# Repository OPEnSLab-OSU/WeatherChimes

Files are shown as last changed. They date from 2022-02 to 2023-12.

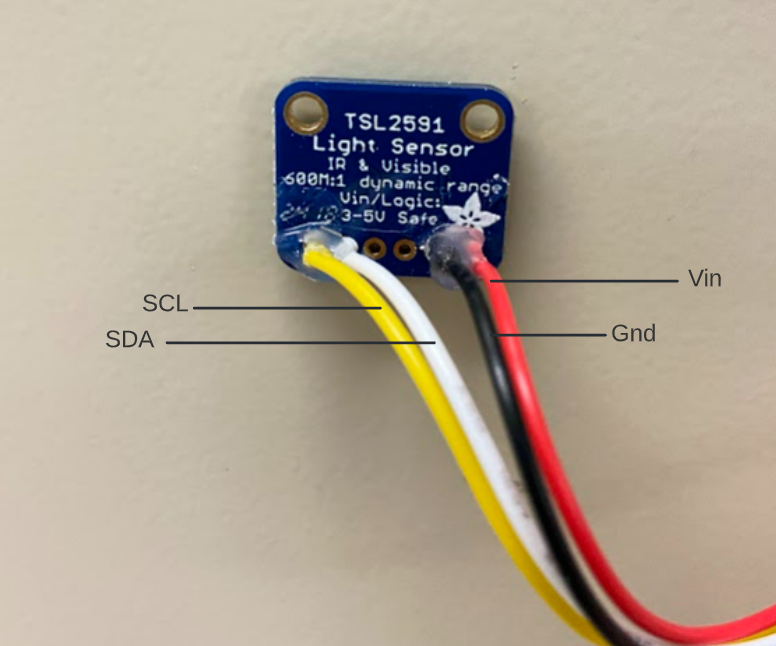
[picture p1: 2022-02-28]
Pictures/Figure 14_TSL JST wiring.PNG

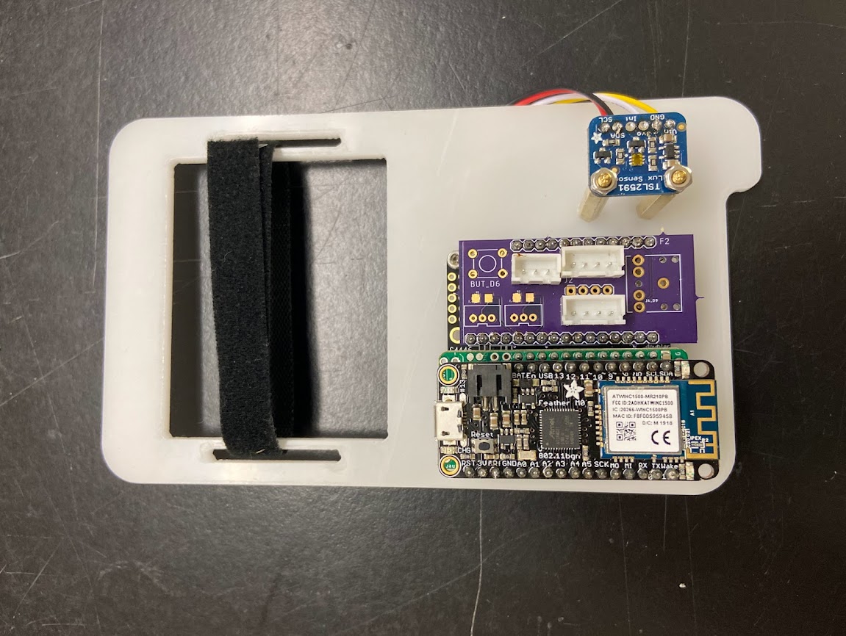
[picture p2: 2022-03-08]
Pictures/Figure 16_Assembled base plate.jpg

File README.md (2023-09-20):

# WeatherChimes
## Completed By: Winnie Woo, Will Richards
---
### [WeatherChimes Wiki](https://github.com/OPEnSLab-OSU/OPEnS-Lab-Home/wiki/WeatherChimes)

WeatherChimes is an Internet of Things (IoT) project that uses Loom from the OPEnS lab to send weather data from an Arduino Feather M0 to [Max](https://cycling74.com/products/max). Much like how a wind chime converts wind information into sound, WeatherChimes strives to use a variety of weather sensors to gather data and then process that information into media like generative music and visual art for users. 

## Build Guide

[WeatherChimes Build Guide PDF](https://docs.google.com/document/d/1GEz6TniiCkyVJEQ1pW2CY4VUsa4j7f_cYcETQBzS96c/edit?usp=sharing)

## Before Installation
Before code can be uploaded to the Feather, download the [Arduino IDE software](https://www.arduino.cc/en/software) and set up the board profile to include the necessary libraries such as Loom, TSL2591, SHT30 and SDI-12, instructions for completing these steps are present in our [Quick Start Guide](https://github.com/OPEnSLab-OSU/Loom-V4). 

## Before Field Deployment
Please refer to the [WeatherChimes Operation Manual](https://docs.google.com/document/d/1b8-toOKHrU17z7gMsPlmyjn5y7iMVSKRvPj8aUgFDfA/edit?usp=sharing) for best practices in understanding and deploying WeatherChimes in the field.

## Setting Up Mosquitto
Mosquitto is an MQTT broker used for handling communication with remote devices over the MQTT protocol
* Download the [Mosquitto Broker](https://mosquitto.org/download/)
* In the directory of the mosquitto folder `C:\Program Files\mosquitto>`, create a mosquitto user/password: the command below will create a user with a name of your choosing, `mosquitto_passwd -c /etc/mosquitto/pwfile *name_of_choice*`.
You will be prompted to enter a password.
* Find the mosquitto.conf file and replace it with the [mosquitto.conf](https://github.com/OPEnSLab-OSU/WeatherChimes/blob/main/MongoDB/mosquitto.conf) file in this repo. For Windows, it can be located in `C:\Program Files\mosquitto\mosquitto.conf`
* In the newly replaced mosquitto.conf now replace line 34 with the path of the pwfile you just created.
* You are now set up to run the Mosquitto exectubale file to host the MQTT broker
<br>

## Setting Up MongoDB Database
[MongoDB Manual](https://docs.mongodb.com/manual/)\
A MongoDB instance should be running on the same server as the MQTT Broker

When data is recieved by the broker it will parse the topic out into the locations that data is stored in the database.

A basic MongoDB setup should suffice in most instances, remote access may be needed which can be completed [here](https://www.digitalocean.com/community/tutorials/how-to-configure-remote-access-for-mongodb-on-ubuntu-20-04)

It is **recommended** that you utilize [MongoDB Clusters](https://www.mongodb.com/basics/clusters) (specifically replica sets) for logging data as this will allow you to utilize the Max8 framework with less work.

<br>

## Connecting MQTT to MongodB using Node-RED

* Download [Node-RED](https://nodered.org/#get-started)
* Locate the `.node-red` folder on your machine. On Windows it can be located at `C:\Users\*your_username*\.node-red`
* Replace the contents of the `.node-red` folder with all the of files in the [Node-RED](https://github.com/OPEnSLab-OSU/WeatherChimes/tree/main/MongoDB/NodeRed) folder of this repository.
* TO run Node-RED, run the command `node-red` in the terminal
* Navigate to 127.0.0.1:1880. You can do this by running "http://localhost:1880/" on a browser. This allows you to interface with the Node-RED “flows”.

### Modifying the Node-RED flow
* The flow should intially look like this:



* The node farthest to the right is the Mongodb node. Click on that node and add your MongoDB cluster that you created earlier into the *Server* field



* Next, you need to specify what broker you want to connect to. Open the MQTT node (It looks like “+/+”). Click the pencil icon next to the Server field, this will allow us to add a new MQTT server. On the following page give it a name. Specify the server address and port (Figure 18) and then under security specify the username and password you use to authenticate with the broker.



<br>

## Loom Installation and MQTT Integration

Uploading the code to the Feather WiFi requires an USB cable. 
Download the code from the WeatherChimes Github repository and put WeatherChimes.ino, arduino_secrets.h and config.h in the same folder and open in Arduino.
Go to Tools >> Board >> Loom SAMD boards V4 >> Loomified Feather M0. Then also check Tools >> Ports and see if the correct port has been selected and the board is appearing on said port. Upload the code to the Feather, after it has finished compiling, check to see if the upload was successful by opening the Arduino IDE serial monitor to see successful connections to the WiFi and MQTT broker as well as the packets of data being sent over the MQTT protocol. 

The system clock needs to be set on the first run or when the Hypnos coin cell battery is reset. 
Within the weatherchimes.ino, line 141:

`80 hypnos.setInterruptDuration(TimeSpan(0, 0, 0, 10));`

The sampling interval could be changed to any duration. From left to right, the numbers represent days, hours, minutes and seconds. 

### Getting the Arduino to connect to the internet and send to Mosquitto

The arduino_secrets.h file also needs to include the MQTT settings. The BROKER_USER and BROKER_PASSWORD correspond to the username and password set on the MQTT broker. The SECRET_BROKER is the server (IP Address / Hostname) where the MQTT Broker is listening. The BROKER_PORT is where that MQTT Broker is listening on the hostname. Finally, the SITE_NAME is not directly related to MQTT but rather the passthrough process as a whole, this tells the MongoDB server which database we should store the data in as it is passed along as the first level in the MQTT topic. 
```
2  // Wifi settings
3  #define SECRET_SSID "Example_SSID"
4  #define SECRET_PASS "Example_Pass"
5
6  // MQTT Settings
7  #define BROKER_USER "Example_User"
8  #define BROKER_PASSWORD "Example_Pass"
9  #define SECRET_BROKER "Example.broker.mosquitto.org"
10 #define BROKER_PORT 1883
11 #define SITE_NAME "WeatherChimes" //The name of the location where these  nodes will be placed
```

The instance number in the WeatherChimes.ino file also needs to be changed that can be done here, where the 1 is the instance number
```
23 Manager manager("Chime", 1);
```
<br>

## Max Patch set-up and usage
The main goal of setting up all of the MQTT connectivity and MongoDB storage of data was to create a seamless functionality to read data into [Max](https://cycling74.com/products/max). 

### Setting up the Max Patch

The MongoDB Connection Max Patch uses a Node.js script to connect to a database and receive live updated information.  
To have the Node.js script running properly ensure that Node is installed. You can do that [here]( https://nodejs.org/en/download/).  
If this is your first time using the MongoDB Max Patch and Node, click the the `Setup` button on the patch to install the necessary packages to run the main script for the patch.  

The Setup button installs the [node package manager (npm)](https://docs.npmjs.com/downloading-and-installing-node-js-and-npm) and MongoDB node package.   
The MongoDB node package can be installed using the line `npm install --mongodb`  

### Using the Max Patch
After completing the setup the user can now use the Max Patch.

To use the MongoDB Connect Max Patch, the user must input four peices of information:
1. MongoDB admin username
2. MongoDB admin password
3. [MongDB unique cluster variable](https://github.com/OPEnSLab-OSU/WeatherChimes#setting-up-mongodb-database)
4. The name of the database they would like to connect to, it should be in the Pass through script. **Example: WeatherChimes**
5. The name of the device (collection) they would like to connect to. This is declared in the config file of the weathercomplete .ino **Example: Chime1**

After all of this information is typed into the corresponding boxes, click Send, which begins the script and connects to the MongoDB database.

Data will be streamed out of the outlet of the patch, and can be used seamlessly with the Loom Sensor Max Patch to read data.

When connected successfully, if the inlet of the Max Patch receives a bang it will output the most recent data that was sent to the connected collection. This also happens upon connecting when Send is clicked.

Further additions can be made to this Patch using the MongoDB node package to get aggregated data outputs and much more. 
  - https://docs.mongodb.com/manual/
  - https://docs.mongodb.com/drivers/node/current/

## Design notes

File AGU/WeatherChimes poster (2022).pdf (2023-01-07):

# WeatherChimes

# Winnie Woo

1

# , Will Richards

1

# , Dr. John S Selker

1,2

# , Dr. Chet Udell

1,2

1Openly Published Environmental Sensing Lab,

### 2Department of Biological & Ecological Engineering, Oregon State University

# PURPOSE

tABSTRACT: Open IoT Weather Station and Data Sonification System

WeatherChimes is an open-source Arduino-programmable, low-cost hardware and software suite that enables real-time access to in-situ environmental sensor data (including light, temperature, relative humidity, and soil moisture) anywhere with a WiFi or 4G internet connection. It also provides applications that translate the data into alternative sensory signals (sound, music, digital art) that enable new insight into natural phenomena and new modalities to monitor and explore these data spaces. Each Chime can measure soil moisture, soil temperature, air temperature and humidity, and solar luminosity, and log data over user-specified intervals online to MongoDB. The Chime is intended to last for 27 days at 15-min sample periods. Addition of a solar cell was accomplished, which can extend operation indefinitely A WiFi-only version of an older model is currently “under review for publication” through HardwareX

Completed WeatherChimes device >>

### Contact Information

Presenter: Winnie Woo
(woow@oregonstate.edu)

Lab Director: Chet Udell
(udellc@oregonstate.edu)

Website/Projects:
(http://www.open-sensing.org/) | Scan Me to See to Our Project Page!

This work was supported via the USDA NIFA Hatch Act (Regular Research Fund, ORE00218A), National Science Foundation (grant no. 2052972) Focused CoPe: Building Community Sensor Networks for Coastal Hazards and Climate Change Impacts in Southeast Alaska, and the National Science Foundation award #1832170. This work was supported via the OSU Engineering and Design for Society initiative with funding by the Provost’s Impact Studio.

The WeatherChimes system operates by:
1. Locating an area where the device enclosure can receive enough sunlight for the light sensor and solar panel.
2. The SHT sensor should be installed ideally vertically to the ground to measure and log data properly. The Teros 12 sensor needs to be inserted horizontally into a 6 in. hole with the long side of the white sensor body vertical and the cable at the top.
3. The barrel jack for the solar panel needs to be plugged into the solar charger.
4. The Osmopod can be dropped into a bucket of water to measure water levels.
5. After battery is plugged in, verifying that the WiFi light on the Feather & Hypnos LED flashes. Log into MongoDB to verify data with appropriate values.

# METHODS: OPERATION

# COMPONENT BREAKDOWN

The Feather WiFi first requests data from the sensors and locally stores that data. After sensor information has been collected, the Feather will initiate a message to a remote MQTT server that is being run locally on an OSU server utilizing the Mosquitto broker. Once we have the data from the broker within Node-Red we can parse from the database and collection name and push to MongoDB. Once the data is within MongoDB, Max8 (by Cycling’74) allows us to handle all communication between Max8 and MongoDB, which opens up numerous possibilities for manipulating and utilizing the data received.

# RESULTS: MongoDB Charts

# ACKNOWLEDGMENTS

- Adafruit Feather M0 WiFi - Microcontroller used to execute code and orchestrate other components.
- LTE board - 4G capabilities for real-time data
- Hypnos - PCB used for time keeping, data-logging and power management.
- TSL2591 - Collects infrared, visible and full-spectrum light.
- Teros 12- collects soil electrical conductivity, soil moisture (volumetric water content) and temperature.
- SHT30 - Collects temperature and humidity.
- 10500 mAh Battery - Provides power to the unit.
- 3D printed components - Base plate for holding components together.
- Pelican case - Used as a waterproof container for electronic components.
- Osmopod - Measures pressure and that can be used to calculate the water levels
- Solar Panel - 6 Watt, 6 V solar panel

# CONCLUSIONS: FUTURE DIRECTION

WeatherChimes demonstrates an open-source option for advancing in-situ data-driven science, automating measurement tasks, uploading and accessing data directly over servers online to decrease the need to interact with field sites to retrieve data and monitor system performance. It also extends these applications to represent and explore data through other modalities for educational purposes. Workshop participants reported the sonification and visualization exercises provided an insightful and engaging introduction to environmental sensors and experiencing their interrelationships using multiple senses. One user shared that hearing something like temperature expressed as a melody turned observing data on a plot into a “time-based experience,” becoming more aware of nuances of movement as the temperature unfolded. Another participant shared that being able to choose the scale of the melody to determine if it sounded happy or sad prompted them to think carefully about the meaning we ascribe to data and why we use data to communicate with others. Further exploration is needed to determine if integrating sonification and alternative visualization tools also yield insights into data research that could not be as easily perceived from a graph at a glance, to help researchers relate with and ascribe meaning to the data in new ways

# Whalefest Workshop (Sitka, Alaska)

WeatherChimes was demonstrated at the Whalefest Workshop at the Sitka Sound Science Center November 2022. Participants used 13 kits connect to MongoDB using our custom applications in Max8, which establishes a connection with specific MongoDB data clusters based on credentials provided by the user. The Max8 Sensor Plotter interfaces below show plots for the SHT30 air temperature (left and right graphs) and relative humidity (middle graph) data over the requested 48-hr period. Keyboard boxes translate the graphs into melodies based on a musical scale and key selected by the user, and red-blue balance of the video in the top right of the figure.

Whalefest Workshop

Each Chime can measure soil moisture, soil electrical conductivity, and soil temperature (Meter GS3); air temperature and humidity (SHT31/SHT30); and solar luminosity (TSL2591), and log data at user defined intervals to the cloud database: MongoDB. Beyond the sensors used in this paper, the Chime is capable of using a variety of analog, digital, I2C, SDI-12, and other serial sensors via footprints on the Printed Circuit Board (PCB) .
WeatherChimes logs real-time sensor data to an internal SD memory card and via network to the MongoDB online database. Typical IoT systems conclude their operation chain at the database layer for plotting and downloading data reports. WeatherChimes goes a step further by incorporating novel data sonification and visualization applications that pull data from MongoDB using NodeJS into a platform called Max8.
Block diagram of WeatherChimes electronics | A Chime installed outside Sitka Sound Science Center

WeatherChimes interface showing data plots from the Sitka Sound Science Center

Solar panel velcroed on Pelican 1060 case | Top view of the PCB

4G LTE board on the underside of the PCB

Data handling flowchart for WeatherChimes

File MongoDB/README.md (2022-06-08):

# MongoDB

This folder contains all code for managing the process of retrieving the data from our Mosquitto MQTT Broker and Passing it Along to our MongoDB Database.

---
<br>

## Node Red
This contains flows and charts to get Node Red up and processing MQTT packets

<br>

## Max Patch
This folder contains all required files to get a Max MSP patch up and running for collecting data from the MongoDB database
 - mongodb.maxpat - Patcher for within MaxMSP itself
 - Mongo2Max.js - JavaScript helper function for the patch should be placed within the javascript subfolder inside the Loom folder for Max

<br>

## Mosquitto
The mosquitto.conf file provides a working configuration for running your own MQTT broker on your own linux server. Most parts of this configuration can be copied over to windows granted the file paths are changed.

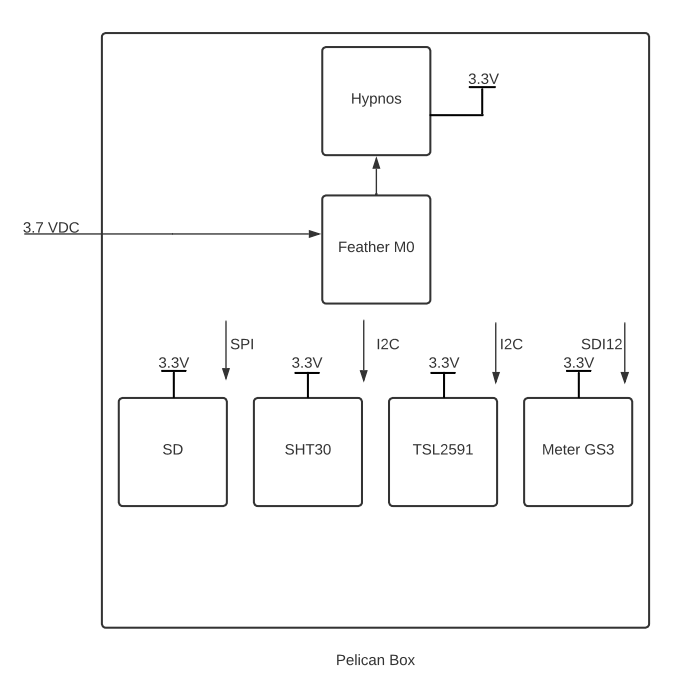
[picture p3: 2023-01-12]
Pictures/Figure 2_Block Diagram of Electronics.PNG

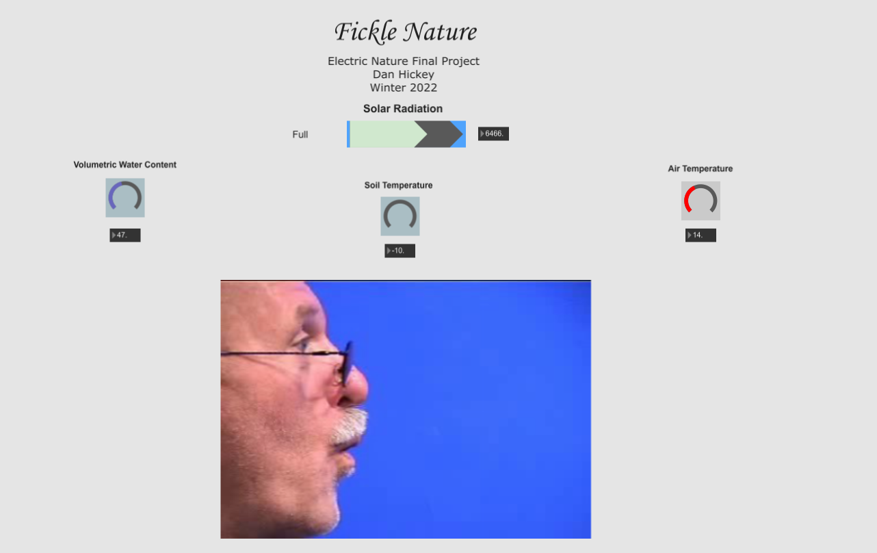
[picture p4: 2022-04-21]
Pictures/Figure 23_Fickle Nature interface pt2.png

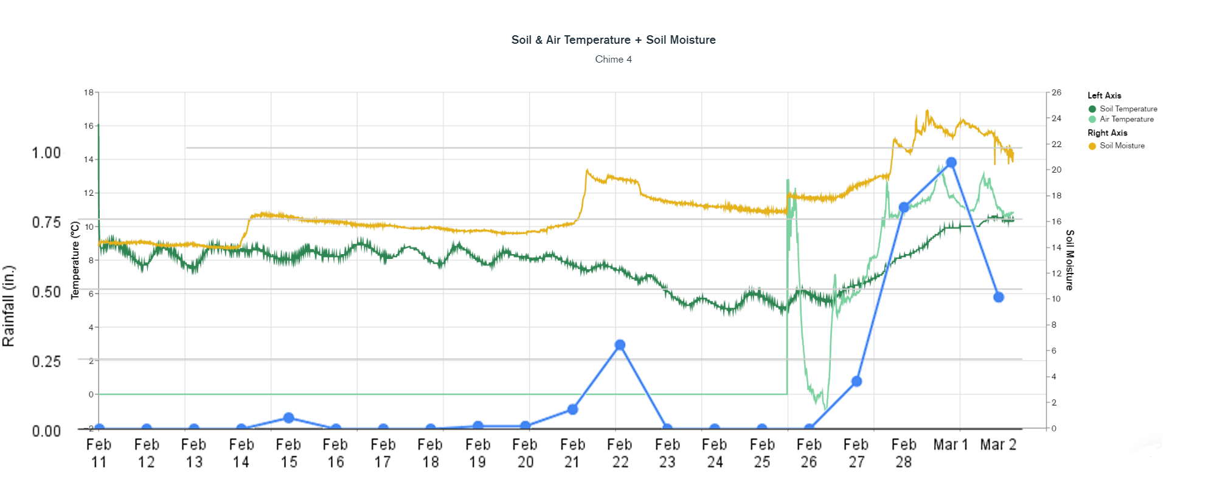
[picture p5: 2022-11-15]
Pictures/Figure 23 Rainfall overlapped with soil moisture MongoDB chart.png

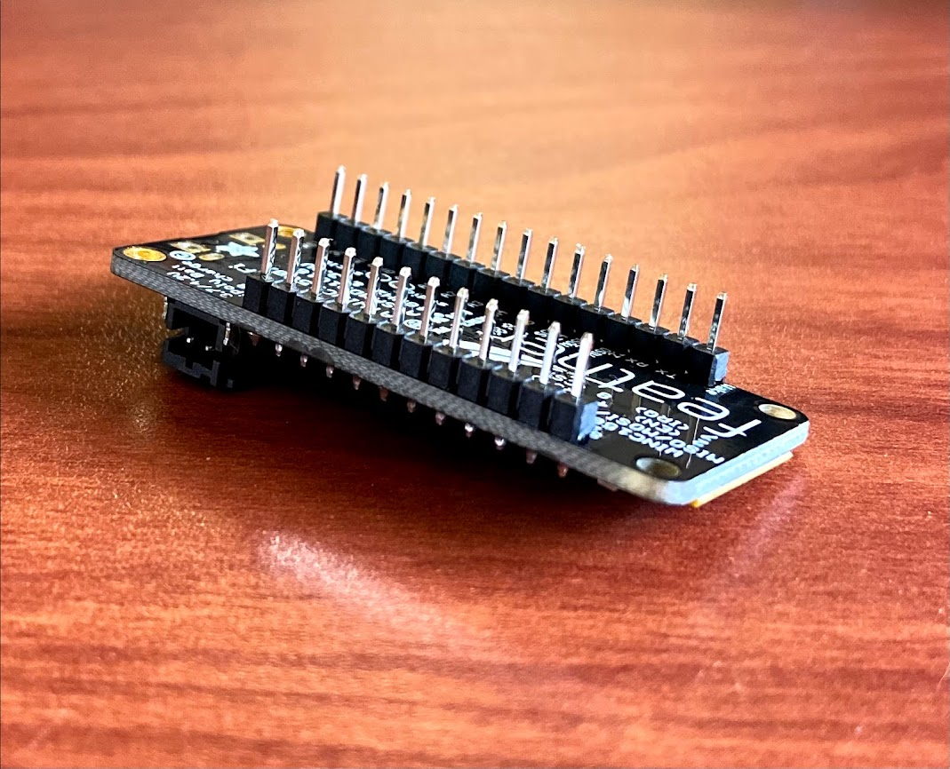
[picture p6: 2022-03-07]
Pictures/Figure 6_Feather male headers.png

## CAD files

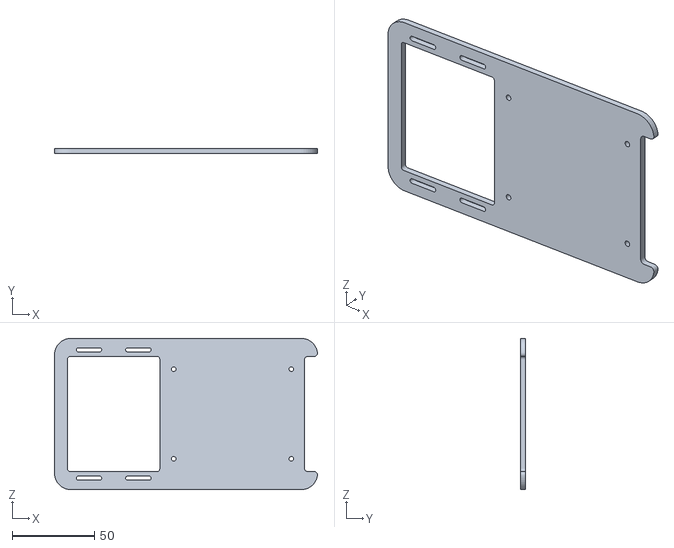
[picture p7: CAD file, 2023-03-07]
Component STL Files/BasePlate v14.stl
159.9 x 3.17 x 92.0

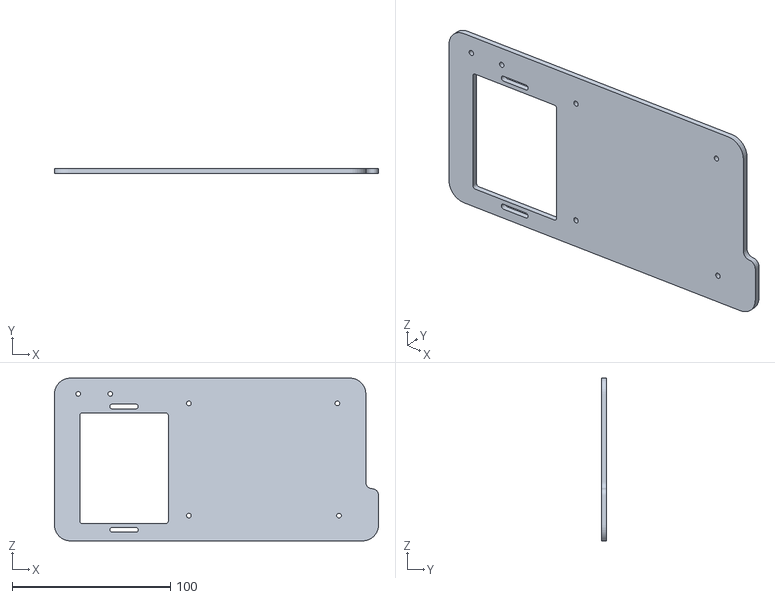
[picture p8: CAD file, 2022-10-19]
Component STL Files/BasePlate_1060 v2.6.stl
205.0 x 3.17 x 103.0

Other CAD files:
Component STL Files/BasePlate_v1.stl

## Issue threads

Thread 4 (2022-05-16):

Chime Testing

winniiew, 2022-05-16:
Chime 5
5/16/2022
```
Logging with MQTT: Yes
Deep-Sleep between Cycles: Yes
Loom Integrated MQTT: No
Disable WiFi between cycles: Yes
Battery or USB: battery
Logging period: 10 seconds
Results: Logged 16 packets and hanged, WiFi no longer on, interrupts isn't triggering so it's not waking up

```

winniiew, 2022-05-16:
Chime 2
5/12/2022
```
Logging with or without MQTT: No
Falling asleep in between cycles: Yes
Using loom integrated MQTT or raw: dirty-integrated
Disable WiFi between cycles: No
Battery or USB: Battery
Logging period: 5 mins
Results: Ran out of battery but was logging to SD
```
Chime 4
5/12/2022
```
Logging with or without MQTT: With MQTT
Falling asleep in between cycles: Yes
Using loom integrated MQTT or raw: dirty-integrated
Disable WiFi between cycles: No
Battery or USB: USB
Logging period: 10 s
Results: ~ 30 packets
```

winniiew, 2022-05-18:
5/17/2022
```
Logging with MQTT:
Deep-Sleep between Cycles:
Loom Integrated MQTT:
Disable WiFi Between Cycles:
Battery or USB:
Logging period:
Results:
```

winniiew, 2022-05-19:
Chime 3
5/19/2022

```
Logging with MQTT: No
Deep-Sleep between Cycles: No
Loom Integrated MQTT: No
Disable Wifi Between Cycles: No
Battery or USB: USB
Logging period:  10 s
Results:
```

WL-Richards, 2022-05-19:
Chime 5
5/19/2022

```
Logging with MQTT: Yes
Deep-Sleep between Cycles: No
Loom Integrated MQTT: No
Disable Wifi Between Cycles: Yes
Battery or USB: USB
Logging period:  10 s
Results:
```

winniiew, 2022-05-24:
Chime 3
5/24/2022
```
Logging with MQTT: No
Deep-Sleep between Cycles: No
Loom Integrated MQTT: No
Disable Wifi Between Cycles: No
Battery or USB: USB
Logging period:  10 s
Results:
```

winniiew, 2022-05-26:
Chime 5
5/26/2022
```
Logging with SD: Yes
Logging with MQTT: Yes
Deep-Sleep between Cycles: No
Loom Integrated MQTT: No
Disable Wifi Between Cycles: Yes
Battery or USB: USB
Logging period:  5 min
Results:
```

Chime 3
5/26/2022
```
Logging with SD: Yes
Logging with MQTT: Yes
Deep-Sleep between Cycles: Yes
Loom Integrated MQTT: No
Disable Wifi Between Cycles: Yes
Battery or USB: Battery
Logging period:  10 mins
Results:
```

Chime 2
5/26/2022
```
Logging with SD: Yes
Logging with MQTT: No
Deep-Sleep between Cycles: Yes
Loom Integrated MQTT: No
Disable Wifi Between Cycles: No
Battery or USB: Battery
Logging period:  10 mins
Results:
```

winniiew, 2022-05-27:
Chime 5
5/27/2022
```
Logging with SD: Yes
Logging with MQTT: Yes
Deep-Sleep between Cycles: No
Loom Integrated MQTT: No
Disable Wifi Between Cycles: No
Battery or USB: USB
Logging period:  5 min
Results:
```

winniiew, 2022-07-06:
7/6/2022

Chime 2
Version 4 Loom
```
Not dirty integrated
Logging with SD: Yes
Logging with MQTT: Yes
Disable WiFi b/t cycles: Yes
Logging period: 5 mins
Battery or USB: USB
Results:
```

Chime 3 (did not find SDI-12*)
Version 3 Loom
```
Dirty integration MQTT
Logging with SD: Yes
Logging with MQTT: Yes
Disable WiFi b/t cycles: Yes
Logging period: 5 or 10 mins
Results:
```

winniiew, 2022-07-20:
7/20/22

Chime 2
LoomV4
*timestamp issue
```
Not dirty integrated
Logging with SD: Yes
Logging with MQTT: Yes
Disable WiFi b/t cycles: Yes
Logging period: 10 s
Battery or USB: USB
Results:
```
Chime 3
LoomV4
*timestamp issue
```
Dirty integration MQTT
Logging with SD: Yes
Logging with MQTT: Yes
Disable WiFi b/t cycles: Yes
Logging period: 10 mins
Battery or USB: Battery
Results:
```

Closed 2023-09-21.

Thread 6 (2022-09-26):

Work with Gurpreet to machine the holes

WL-Richards, 2022-09-26:
4 holes: Teros (3-pin), SHT (4-pin), SHT, Solar (2.1mm cable barrel jack)

winniiew, 2022-10-17:
-Panel mount barrel jack
-adapter cable

Closed 2022-10-24.

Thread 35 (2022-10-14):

Measure and find correct standoffs for solar charger/4G board

winniiew, 2022-10-14:

winniiew, 2022-10-17:
M2.5x6mm+6mm + ~2mm nut

Closed 2022-10-19.

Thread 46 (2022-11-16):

Feature: Auto Teros 10, 11, 12 on same port

udellc, 2022-11-16:
It would be nice to dedicate a single port on our logger to handling either sensors from METER that could be either an SDI12 type or Analog type (e.g. for Teros10 analog, or Teros11 or 12 SDI12). We have ports that can act either as SDI-12 digital pins, or analog inputs.
On startup, check first to see if the connected device(s) is/are SID-12 by sending a message to that port to prompt SDI12 devices to respond. If no response, then we assume attached device is analog and we set the pin as such.
This may be achieved by setting a check in our Loom SDI12 handler, that if we receive no response from an SDI12 query, we set the pin to behave as 12-bit analog input. It might not report Dielectric or VWC from analog, but it would be functionally reporting millivolt data, which could be converted in post processing.
Just an idea. Further discussion needed.

udellc, 2023-09-21:
Hi Alexei, do we have code that actually does this? Or are we closing the issue as not relevant at this time? I'd like to keep this open as a possibility for future coding after Whalefest.

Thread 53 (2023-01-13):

Training program - set up a time

winniiew, 2023-01-13:

winniiew, 2023-01-13:
1. Feather M0 and blink LED (**week 2**)
2. print I2C /analog/ SDI sensor data to serial monitor
3. wire Hypnos - log sensor to SD card (**week 3**)
4. hypnos - interrupts/sleep
5. LoRa radio - send from one M0 to another (**week 4**)

Closed 2023-02-06.

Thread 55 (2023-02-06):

Irish Bend Covered Bridge Chime fix

winniiew, 2023-02-06:

winniiew, 2023-02-06:
Detach the stream sensor, SHT30, tipping bucket, main box

Closed 2023-02-13.

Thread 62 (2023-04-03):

Fix RBG Sensor

alexeiaburgos, 2023-04-03:

Closed 2023-04-03.

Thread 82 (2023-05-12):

Order Redesigned PCBs and Adapter Boards

alexeiaburgos, 2023-05-12:

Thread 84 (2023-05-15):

Troubleshoot the hanging WeatherChimes that has issue with 4G board

alexeiaburgos, 2023-05-15:

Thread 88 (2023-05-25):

Luca Inspect Osmopod Sensors & Tighten Screws in WeatherChimes

alexeiaburgos, 2023-05-25:

Closed 2023-06-06.

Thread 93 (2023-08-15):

Test and Validate I2C Counter with breadboard

alexeiaburgos, 2023-08-15:
- [ ] Solder Counter to Breakout board
- [ ] Run Raw I2C Counter Example
- [ ] Loomify with Will

alexeiaburgos, 2023-08-15:
1. Solder Counter to Breakout board
2. Run Raw I2C Counter Example
3. Loomify with Will

Closed 2024-01-10.

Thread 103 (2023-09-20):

Print Base Plates

alexeiaburgos, 2023-09-20:

udellc, 2023-09-21:
@alexeiaburgos @lrianda , these may be laser cut! John fixed the laser cutter with Hannah - we should have material acrylic for these marked in the big storage closet in Gilmore annex lab with the other laser cuter stock.

Closed 2023-10-27.

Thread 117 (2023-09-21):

Low-priority Feature request: Dynamic 4G upload time based on rainfall

udellc, 2023-09-21:
For Chimes using rainfall, hourly reports over 4G may be sufficient to extend battery life, but will want to dynamically increase reports to 4G sampling rate to once every 15 or even 10min based on a high rainfall threshold (TBD by the science team).
This would entail adding code to check if Tipping Bucket is even being used or not - and if so, set the RTC wakeup time for next cycle after checking and calculating the rainfall rate for the last sample.
This may require a readjustment of how we calculate rainfall rate over the hour, instead of and array of 4 values each representing 15min, we will need to analyze the accumulated rainfall based on timestamp.
Low priority, but needs to be an active issue till addressed in future.

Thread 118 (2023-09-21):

Remeasure and reconfirm all hole placements / diameters

alexeiaburgos, 2023-09-21:
Remove cable glands and barrel jack from existing chimes box. Write down measurements before drilling.

alexeiaburgos, 2023-09-21:
- [ ] Add solar panel DC barrel jack mount to case hole (BE SURE BARREL JACK HOLE IS DIFFERENT SIZE THAN CABLE GLAND HOLE)

Closed 2023-09-29.

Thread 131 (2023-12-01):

Discuss mitigation practices for DO circuits

alexeiaburgos, 2023-12-01:
- Brainstorm if there's any hardware implementation or design modification on our DO PCB to protect our DO circuit
- What can we add to our testing workflow to mitigate this issue?
- Determine why our DO circuit is continuing to get damaged?

alexeiaburgos, 2023-12-01:
Note 12/1 - Found that a pin on the EZO isolator board is left floating (OFF pin). Data sheet says that it can be left floating, but we should tie it to VCC in our PCB. Will need to do further testing to see if this will protect our DO Circuit

Closed 2024-01-02.

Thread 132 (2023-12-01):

I2C Extender Board Testing

alexeiaburgos, 2023-12-01:
- [ ] Stage #1 of Testing:

> - [ ] Test I2C Extender with ethernet cable that is less than 3 ft.
> - [ ] Use a variable I2C sensor (i.e. Accelerometer)

- [ ] Stage #2 of Testing:

> - [ ] Test I2C Extender with ethernet cable with a minimum length of 20 ft.
>- [ ] Check the current draw at the end of ethernet cable at this length
> - [ ] Do this same current draw test same test with with ethernet cable with min. length of 30 ft.

- [ ] Stage #3 of Testing (Official Field Testing):

> - [ ] Test I2C Extender with ethernet cable with a minimum length of 30 ft.
>- [ ] Attach Osmopod and/or EZO DO Probe and install at a field site

alexeiaburgos, 2023-12-01:
Within Stage 1 testing, the receiving end of the board is at 1.8V voltage, seeing a voltage drop from the wire. The ethernet cable has an internal resistance between the VCC & GND of 350 ohm. To mitigate this voltage drop, we can decrease the current flowing through the cable by increasing the resistor values of the receiving and transmitting boards by a factor of 10. This will decrease the flow of current that is approximatively 3 mA to 0.3 mA, thus reducing the voltage drop across ethernet cable

alexeiaburgos, 2023-12-08:
Stage 1 - Used another ethernet cable, the I2C Extender was able to power the sensor and communicate properly. The internal resistance between VCC & GND was zero measured at 0 ohms across the wire. The internal resistance between wires on the VCC/GND was measured at 7 ohms.

alexeiaburgos, 2024-01-02:
Stage 2 - Casey tested I2C Extender with SHT: Current draw was 1mAh and 9mWh over 3 minutes

alexeiaburgos, 2024-01-09:
Stage 3 - Tested with Osmopod w/ cable length of 20ft. Instantaneous Current draw was 32 mA. Osmopods are having issues initializing

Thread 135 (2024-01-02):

Reach Out to Replace Chime Battery in SSSC

alexeiaburgos, 2024-01-02:

Closed 2024-01-08.

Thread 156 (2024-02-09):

Troubleshoot Chime2 (Osmopod on PCB needs to be resoldered)  & then reprogram with NTP code

alexeiaburgos, 2024-02-09:

CaseyJ37, 2024-02-16:
Osmopod on PCB has been fixed.

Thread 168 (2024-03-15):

Redesign Osmopod board with changes and order necessary components for building

alexeiaburgos, 2024-03-15:

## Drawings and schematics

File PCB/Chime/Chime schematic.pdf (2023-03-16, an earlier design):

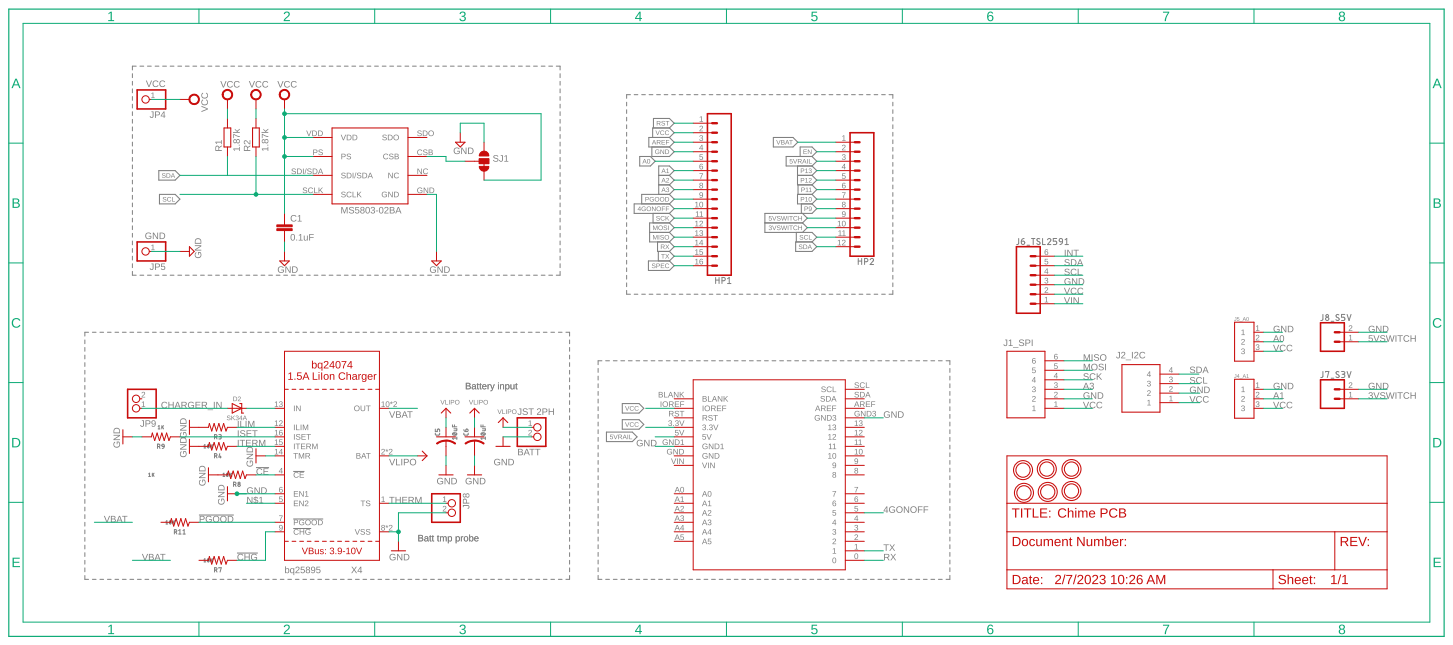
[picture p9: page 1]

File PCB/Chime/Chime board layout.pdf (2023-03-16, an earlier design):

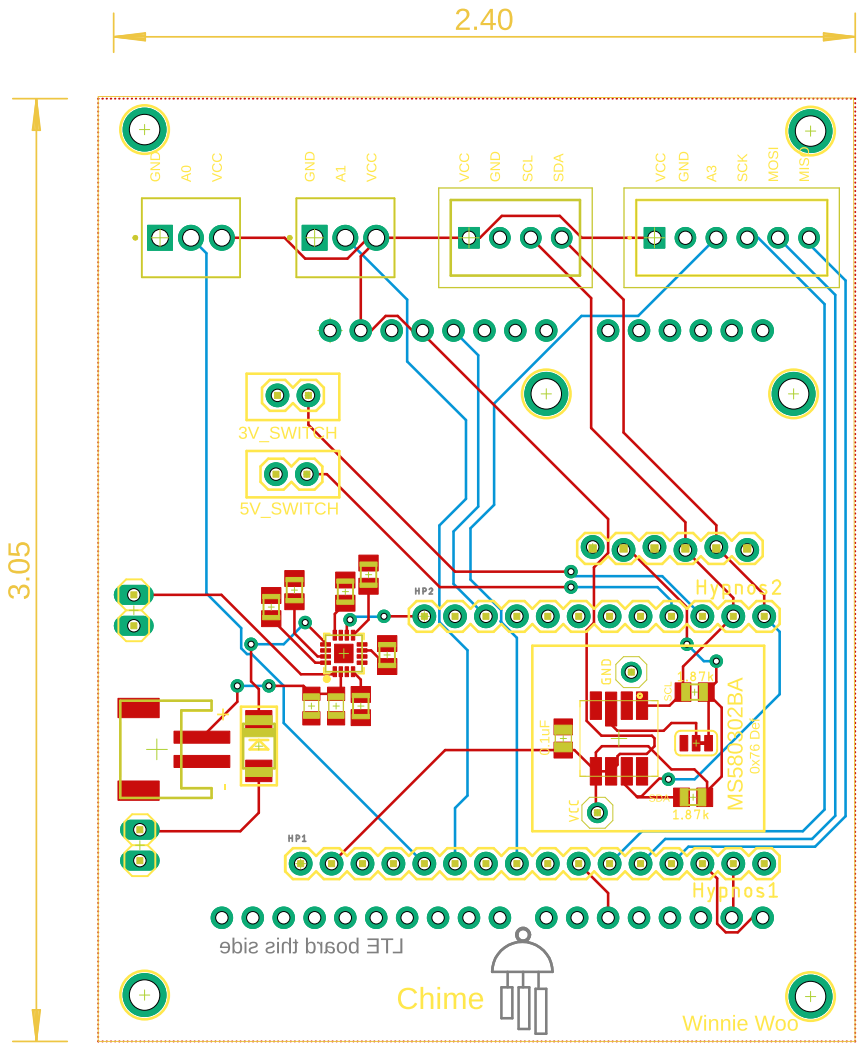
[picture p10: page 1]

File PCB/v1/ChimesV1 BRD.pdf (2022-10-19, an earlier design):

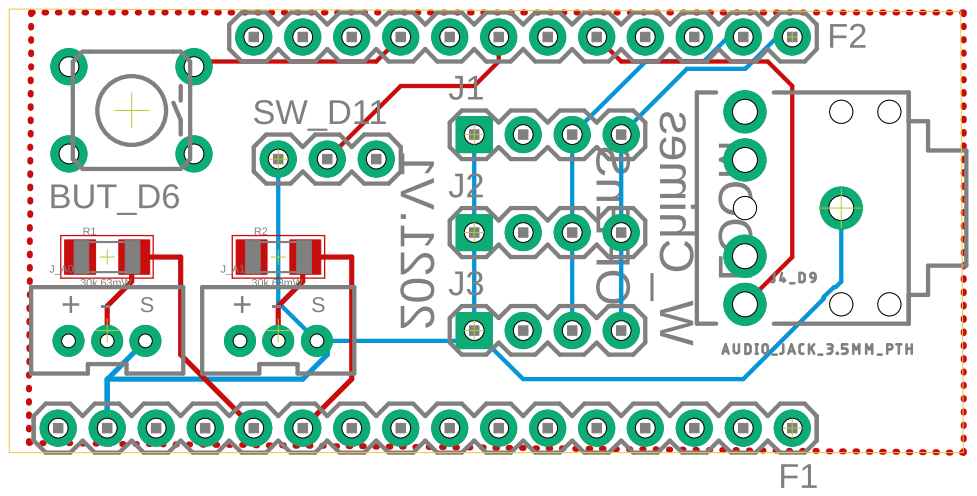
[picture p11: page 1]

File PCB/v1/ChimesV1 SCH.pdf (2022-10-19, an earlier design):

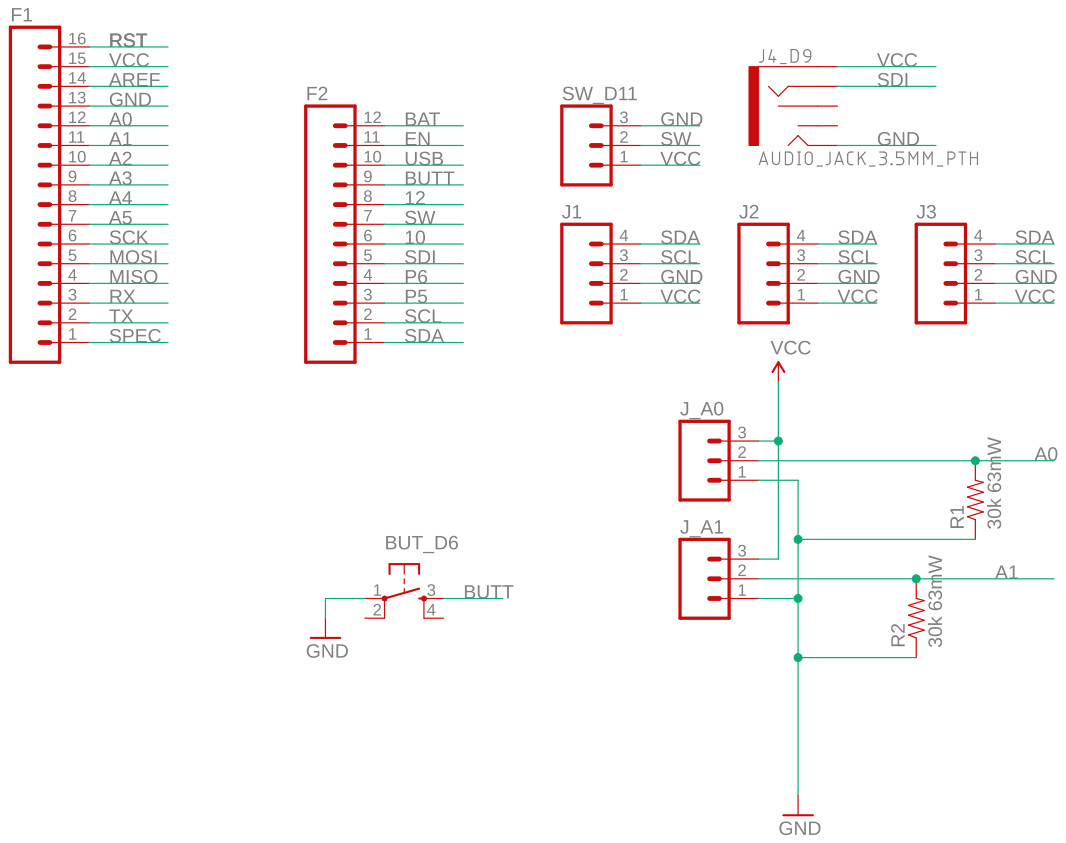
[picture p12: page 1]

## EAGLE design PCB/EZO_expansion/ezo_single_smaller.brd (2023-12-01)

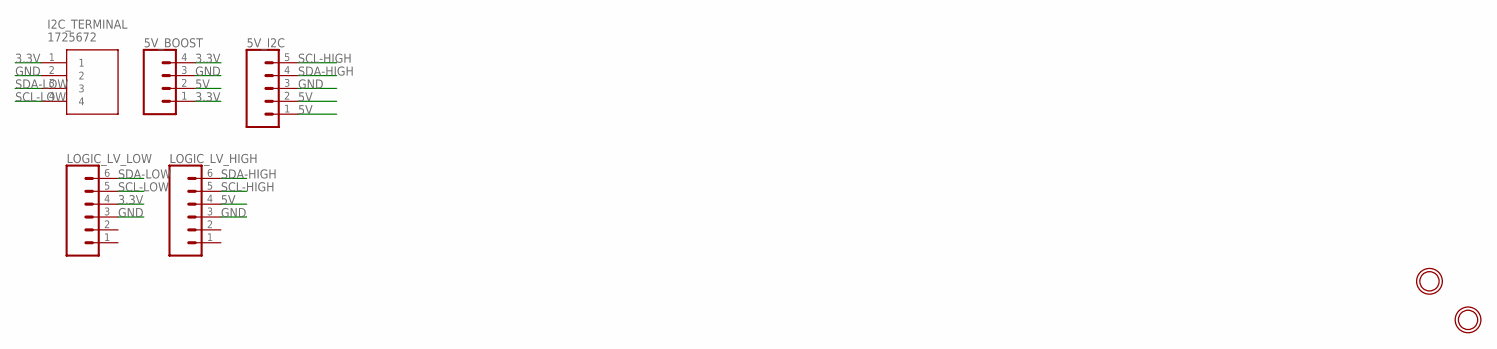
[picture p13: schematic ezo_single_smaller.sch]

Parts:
5V_BOOST: CONN_04PTH; 1X04
5V_I2C: CONN_05PTH; 1X05
I2C_TERMINAL: 1725672
LOGIC_LV_HIGH: CONN_06SILK_FEMALE_PTH; 1X06
LOGIC_LV_LOW: CONN_06SILK_FEMALE_PTH; 1X06
U$1, U$3: MOUNTINGHOLE2.5; MOUNTINGHOLE_2.5_PLATED

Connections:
3.3V: 5V_BOOST.1, 5V_BOOST.4, I2C_TERMINAL.1, LOGIC_LV_LOW.4
5V: 5V_BOOST.2, 5V_I2C.1, 5V_I2C.2, LOGIC_LV_HIGH.4
GND: 5V_BOOST.3, 5V_I2C.3, I2C_TERMINAL.2, LOGIC_LV_HIGH.3, LOGIC_LV_LOW.3
SCL-HIGH: 5V_I2C.5, LOGIC_LV_HIGH.5
SCL-LOW: I2C_TERMINAL.4, LOGIC_LV_LOW.5
SDA-HIGH: 5V_I2C.4, LOGIC_LV_HIGH.6
SDA-LOW: I2C_TERMINAL.3, LOGIC_LV_LOW.6

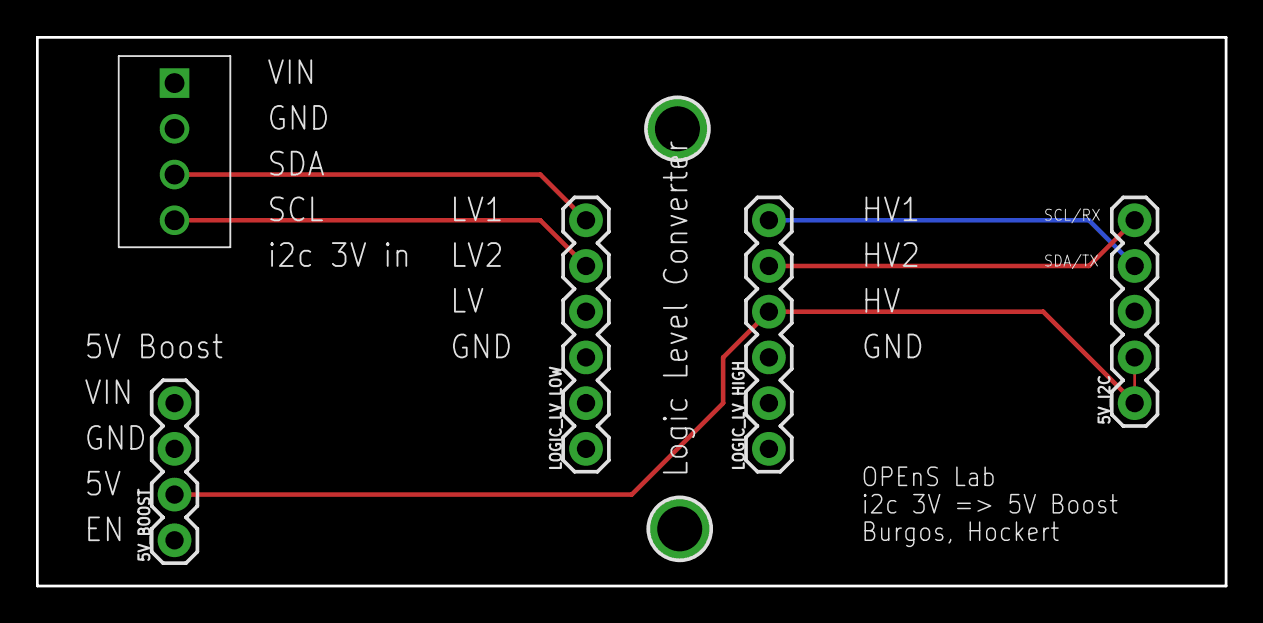
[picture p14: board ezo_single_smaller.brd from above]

Board: 2 copper layers, 66.0 x 30.5 mm, 7 parts (0 on the bottom side), 7 nets.

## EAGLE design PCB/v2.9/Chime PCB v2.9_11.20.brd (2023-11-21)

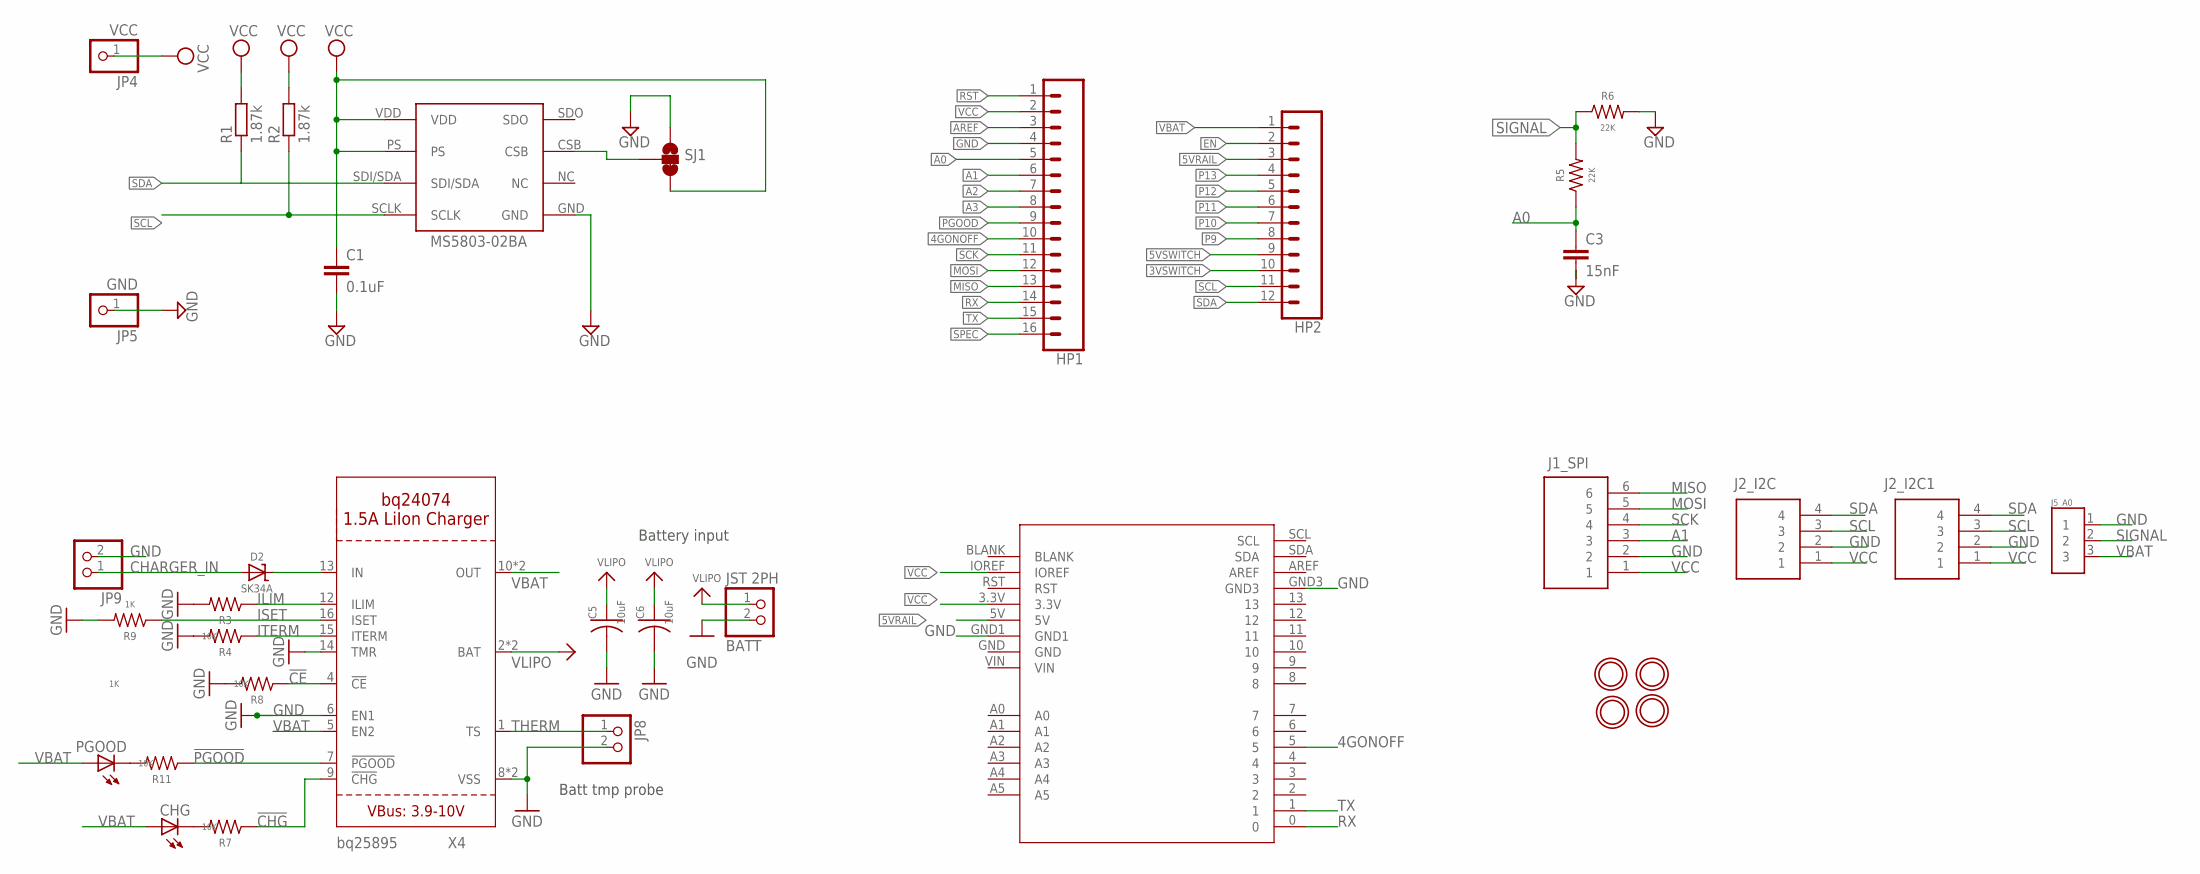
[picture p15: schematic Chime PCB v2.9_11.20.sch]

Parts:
BATT: JST 2PH; JST-PH-2-SMT-RA
C1: 0.1uF; C0805
C3: 15nF; C0805
C5, C6: 10uF; C0805K
CHG: LEDCHIPLED_0805; CHIPLED_0805
D2: SK34A; SMADIODE
HP1: CONN_16; 1X16
HP2: CONN_12; 1X12
J1_SPI: 1725698
J2_I2C, J2_I2C1: 1725672
J5_A0: 282834-3; TE_282834-3
JP4: VCC; 1X01
JP5: GND; 1X01
JP8, JP9: PINHD-1X2; 1X02
PGOOD: PGOOD; CHIPLED_0805
R1, R2: 1.87k; R0805
R3, R9: 1K; M0805
R4, R7, R8, R11: 10K; M0805
R5, R6: 22K; M0805
SJ1: JUMPER-SMT_3_1-NC_TRACE_SILK; SMT-JUMPER_3_1-NC_TRACE_SILK
U1: MS5803-02BA
U$1: LTE_BOARD; LTE_BOARD_FOOTPRINT
U$2, U$3, U$4, U$5: MOUNTINGHOLE2.5; MOUNTINGHOLE_2.5_PLATED
X4: BQ24074; QFN16_3MM

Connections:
3VSWITCH: HP2.10
4GONOFF: HP1.10, U$1.5
5VRAIL: HP2.3, U$1.5V
5VSWITCH: HP2.9
!CE: R8.1, X4.4 (!CE)
!CHG: R7.1, X4.9 (!CHG)
!PGOOD: R11.1, X4.7 (!PGOOD)
A0: C3.1, HP1.5, R5.1
A1: HP1.6, J1_SPI.3
A2: HP1.7
A3: HP1.8
AREF: HP1.3
CHARGER_IN: D2.A, JP9.1
EN: HP2.2
GND: BATT.2 (1), C1.2, C3.2, C5.2, C6.2, HP1.4, J1_SPI.2, J2_I2C.2, J2_I2C1.2, J5_A0.1, JP5.1, JP8.2, JP9.2, R3.2, R4.2, R6.2, R8.2, R9.2, SJ1.1, U1.GND, U$1.GND1, U$1.GND3, X4.6 (EN1), X4.8 (VSS), X4.14 (TMR), X4.THERMAL (VSS)
ILIM: R3.1, X4.12 (ILIM)
ISET: R9.1, X4.16 (ISET)
ITERM: R4.1, X4.15 (ITERM)
MISO: HP1.13, J1_SPI.6
MOSI: HP1.12, J1_SPI.5
unnamed: D2.C, X4.13 (IN)
unnamed: SJ1.2, U1.CSB
unnamed: PGOOD.C, R11.2
unnamed: CHG.C, R7.2
P9: HP2.8
P10: HP2.7
P11: HP2.6
P12: HP2.5
P13: HP2.4
PGOOD: HP1.9
RST: HP1.1
RX: HP1.14, U$1.0
SCK: HP1.11, J1_SPI.4
SCL: HP2.11, J2_I2C.3, J2_I2C1.3, R2.1, U1.SCLK
SDA: HP2.12, J2_I2C.4, J2_I2C1.4, R1.1, U1.SDI/SDA
SIGNAL: J5_A0.2, R5.2, R6.1
SPEC: HP1.16
THERM: JP8.1, X4.1 (TS)
TX: HP1.15, U$1.1
VBAT: CHG.A, HP2.1, J5_A0.3, PGOOD.A, X4.5 (EN2), X4.10 (OUT), X4.11 (OUT)
VCC: C1.1, HP1.2, J1_SPI.1, J2_I2C.1, J2_I2C1.1, JP4.1, R1.2, R2.2, SJ1.3, U1.PS, U1.VDD, U$1.3.3V, U$1.IOREF
VLIPO: BATT.1 (2), C5.1, C6.1, X4.2 (BAT), X4.3 (BAT)

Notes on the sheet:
Batt tmp probe
Battery input

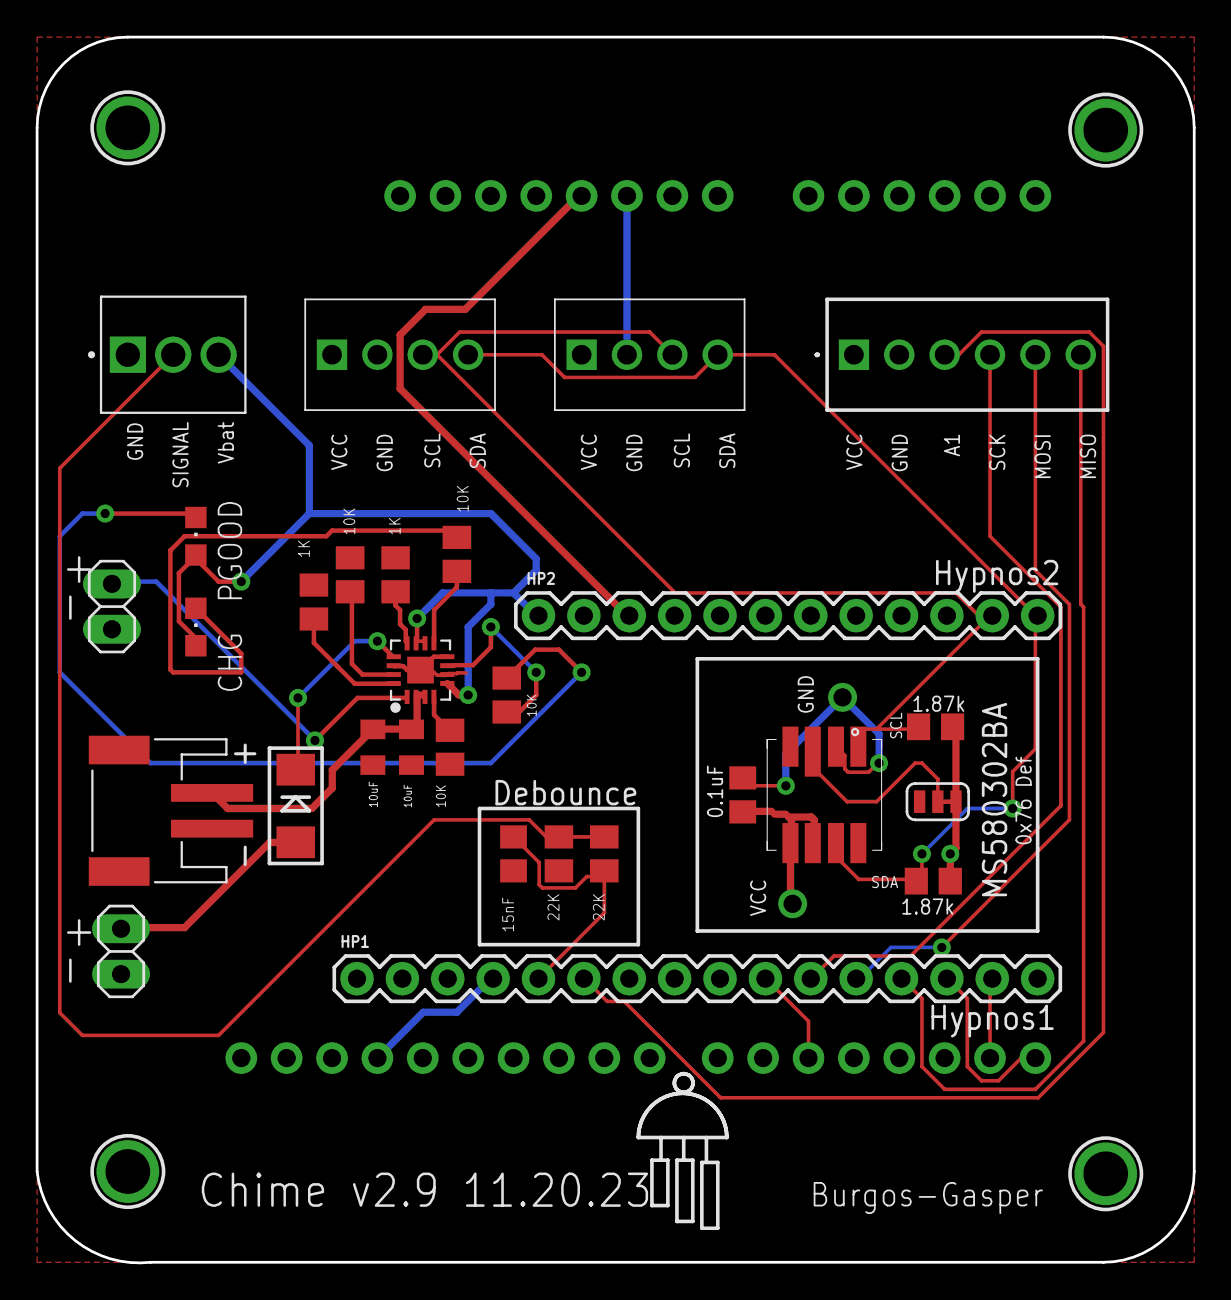
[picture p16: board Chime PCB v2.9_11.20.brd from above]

Board: 2 copper layers, 64.8 x 68.6 mm, 36 parts (1 on the bottom side), 28 nets.

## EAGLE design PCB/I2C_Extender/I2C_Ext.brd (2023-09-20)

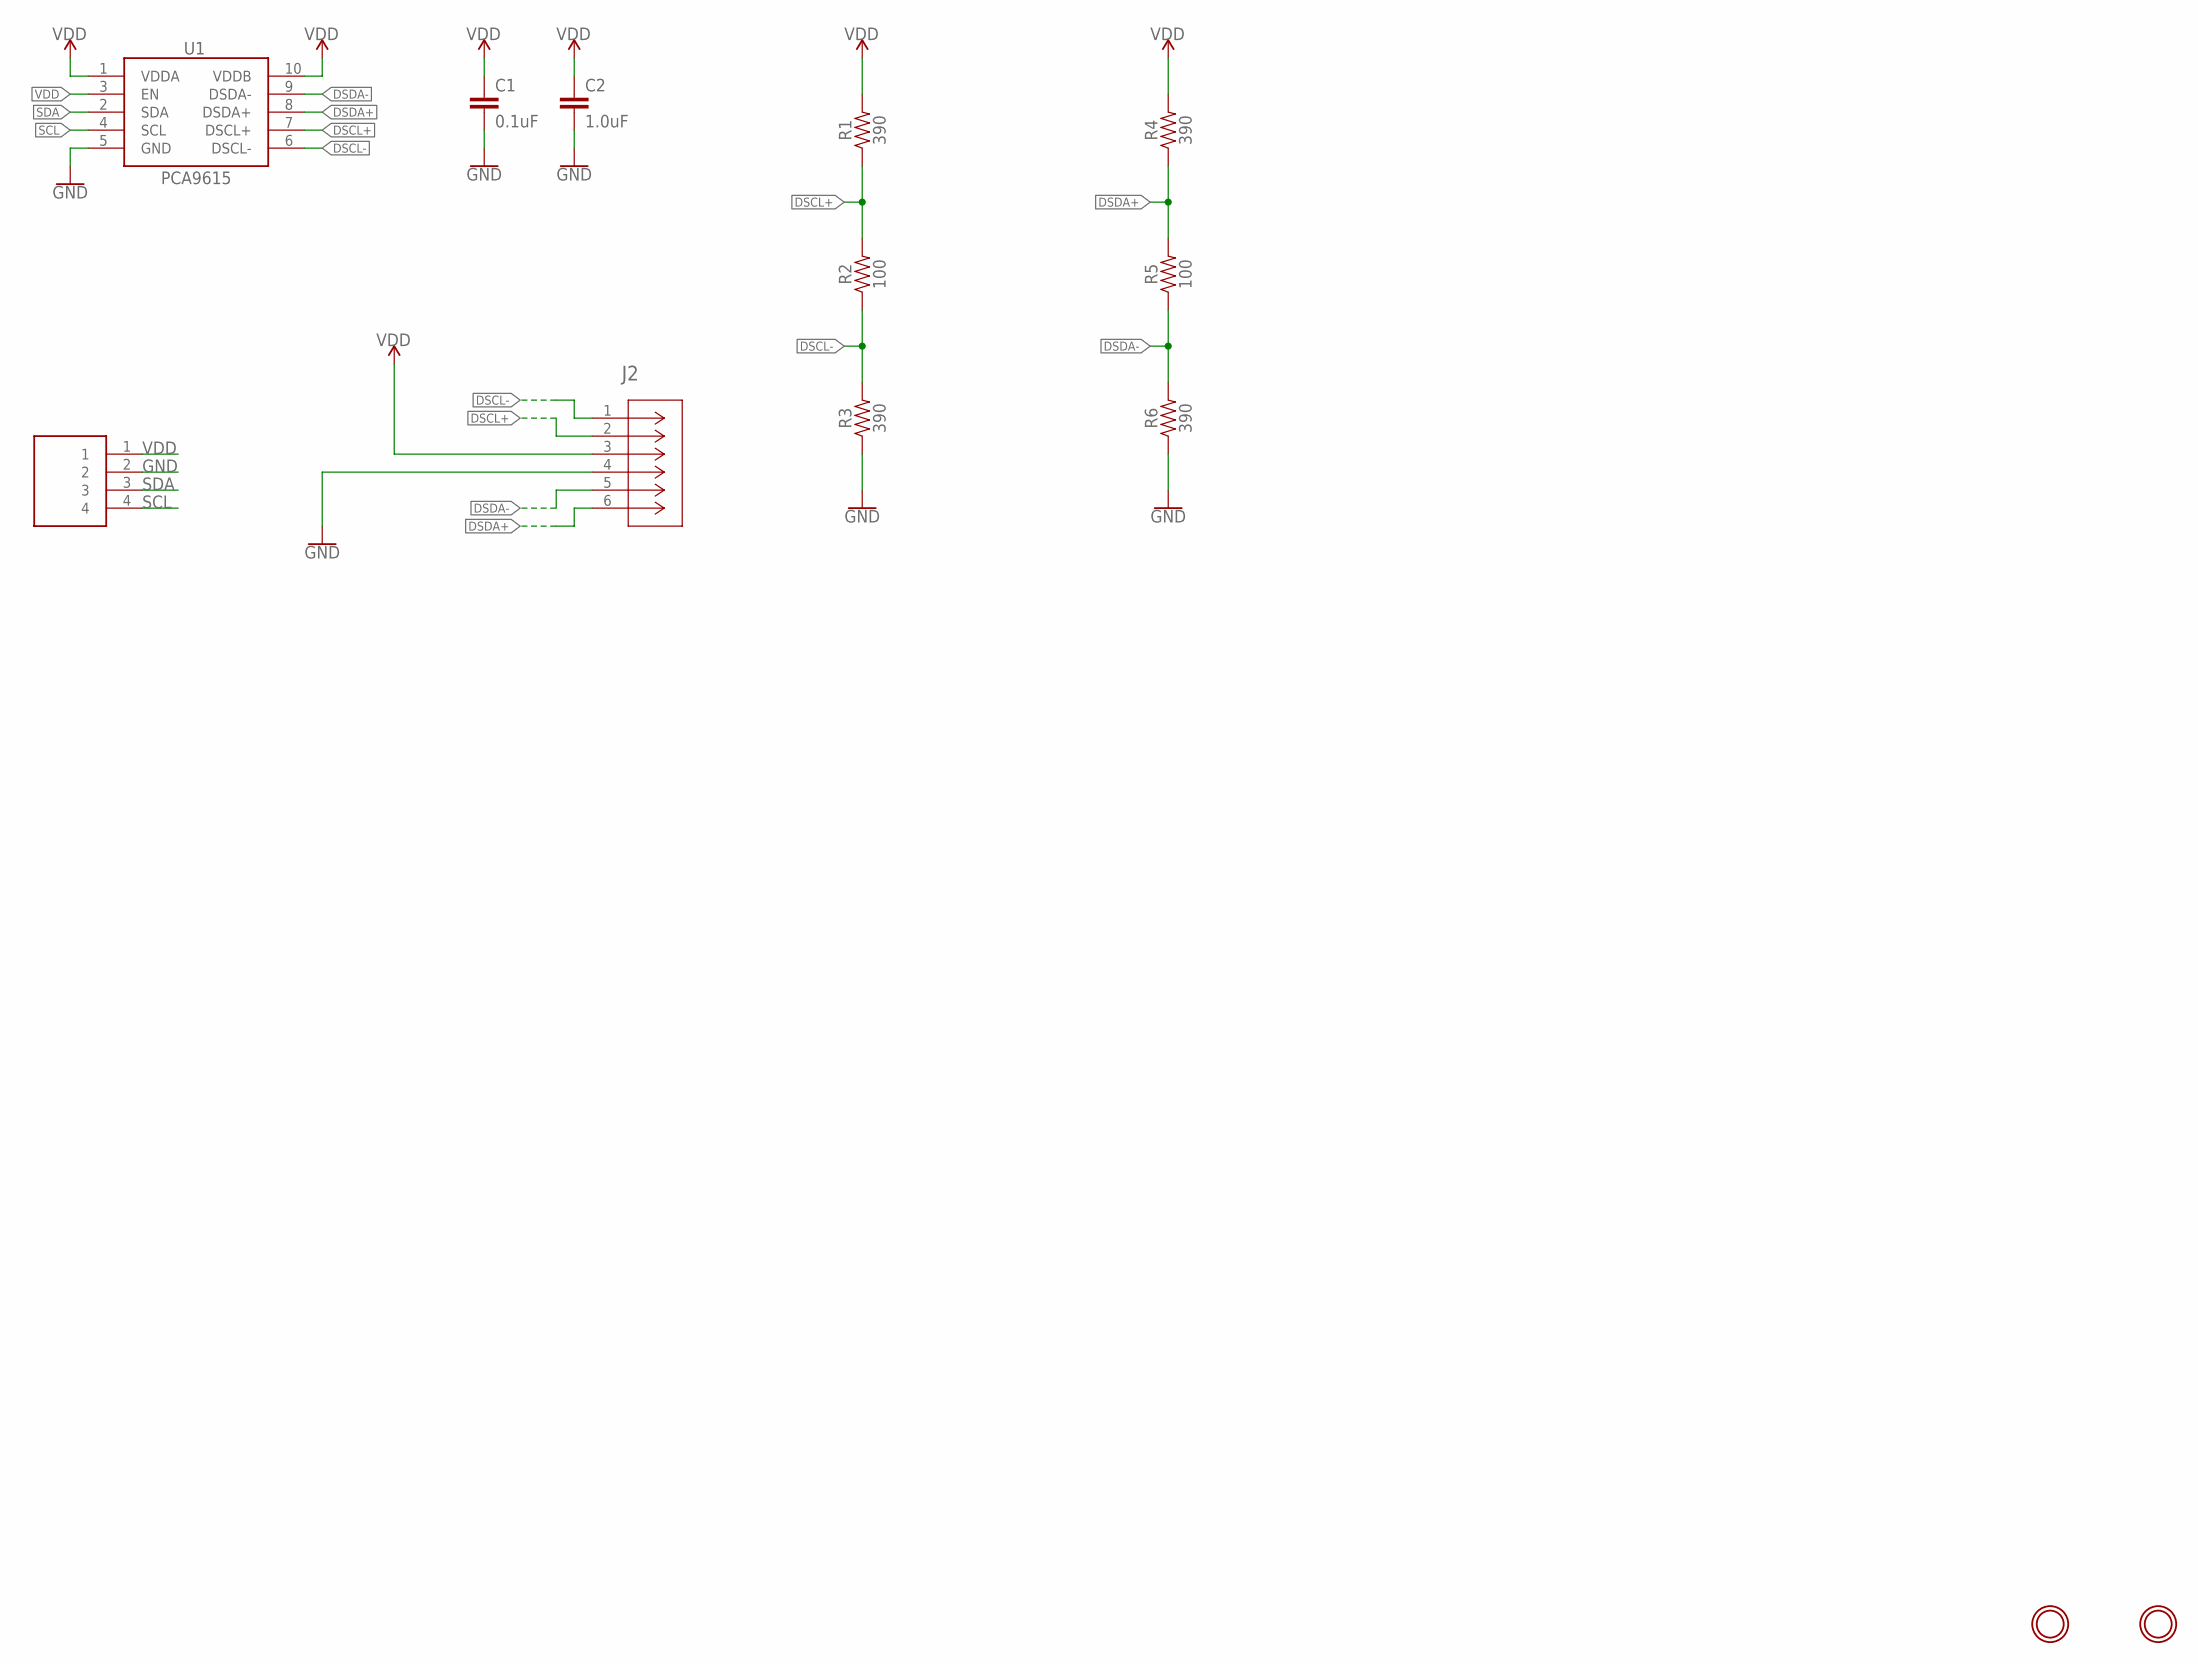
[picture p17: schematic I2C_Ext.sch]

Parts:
C1: 0.1uF; 0603
C2: 1.0uF; 0603
J1: 1725672
J2: 1725698; CONN_1725698_PXC
R1, R3, R4, R6: 390; 0603
R2, R5: 100; 0603
U1: PCA9615; TSSOP10
U$1, U$3: MOUNTINGHOLE2.5; MOUNTINGHOLE_2.5_PLATED

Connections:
DSCL+: J2.2, R1.1, R2.2, U1.7 (DSCL+)
DSCL-: J2.1, R2.1, R3.2, U1.6 (DSCL-)
DSDA+: J2.6, R4.1, R5.2, U1.8 (DSDA+)
DSDA-: J2.5, R5.1, R6.2, U1.9 (DSDA-)
GND: C1.2, C2.2, J1.2, J2.4, R3.1, R6.1, U1.5 (GND)
SCL: J1.4, U1.4 (SCL)
SDA: J1.3, U1.2 (SDA)
VDD: C1.1, C2.1, J1.1, J2.3, R1.2, R4.2, U1.1 (VDDA), U1.3 (EN), U1.10 (VDDB)

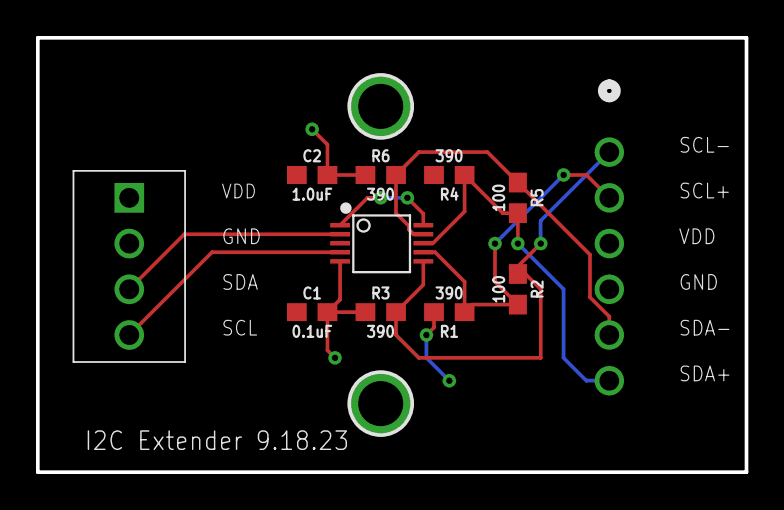
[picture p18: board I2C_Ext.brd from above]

Board: 2 copper layers, 39.4 x 24.1 mm, 13 parts (1 on the bottom side), 8 nets.

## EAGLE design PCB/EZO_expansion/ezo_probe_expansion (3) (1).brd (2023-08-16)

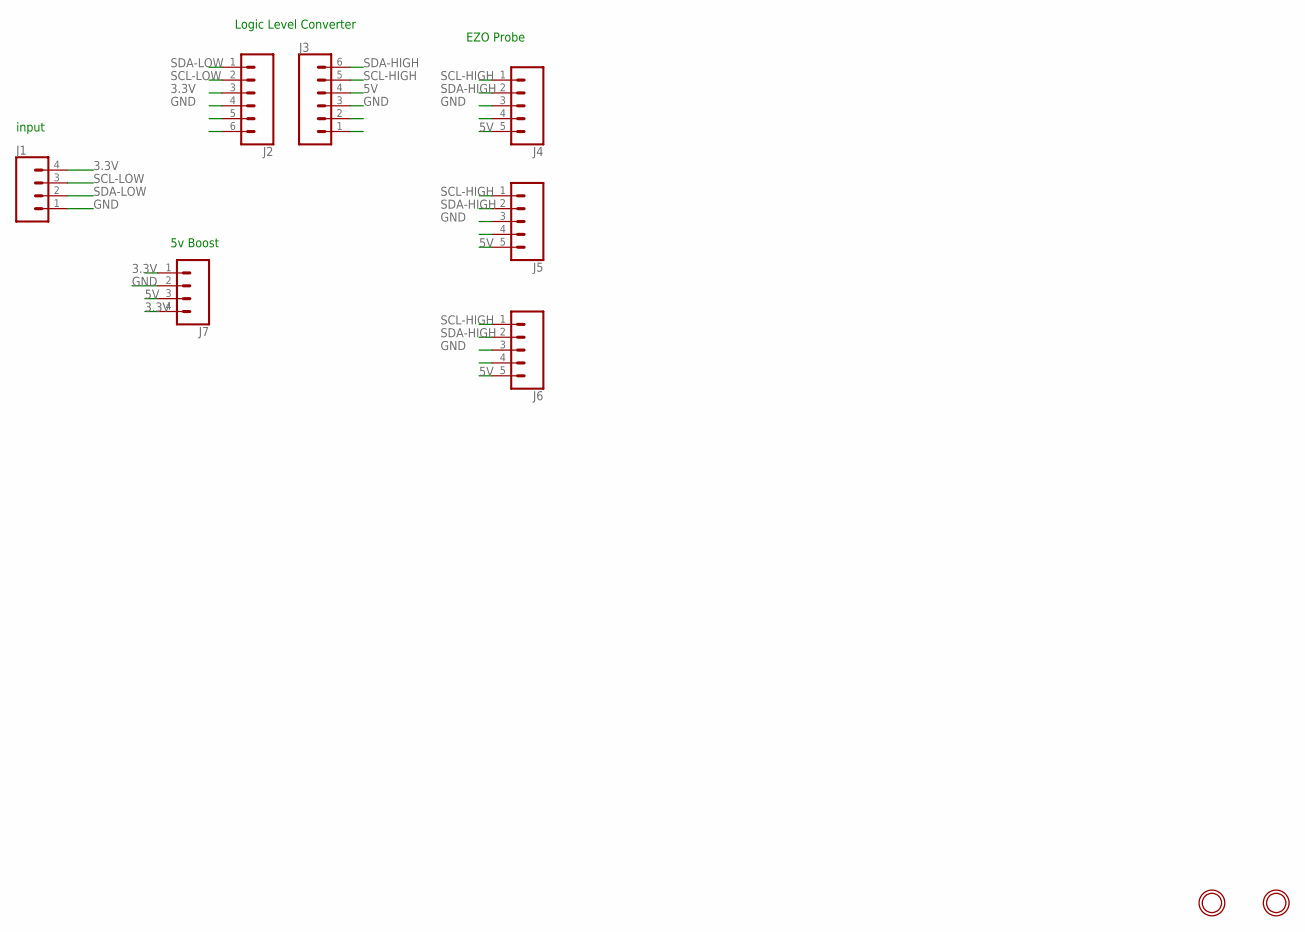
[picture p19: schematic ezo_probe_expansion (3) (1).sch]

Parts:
J1, J7: CONN_04PTH; 1X04
J2, J3: CONN_06SILK_FEMALE_PTH; 1X06
J4, J5, J6: CONN_05PTH; 1X05
U$1, U$2: MOUNTINGHOLE2.5; MOUNTINGHOLE_2.5_PLATED

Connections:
3.3V: J1.4, J2.3, J7.1, J7.4
5V: J3.4, J4.5, J5.5, J6.5, J7.3
GND: J1.1, J2.4, J3.3, J4.3, J5.3, J6.3, J7.2
SCL-HIGH: J3.5, J4.1, J5.1, J6.1
SCL-LOW: J1.3, J2.2
SDA-HIGH: J3.6, J4.2, J5.2, J6.2
SDA-LOW: J1.2, J2.1

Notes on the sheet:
input
Logic Level Converter
EZO Probe
5v Boost

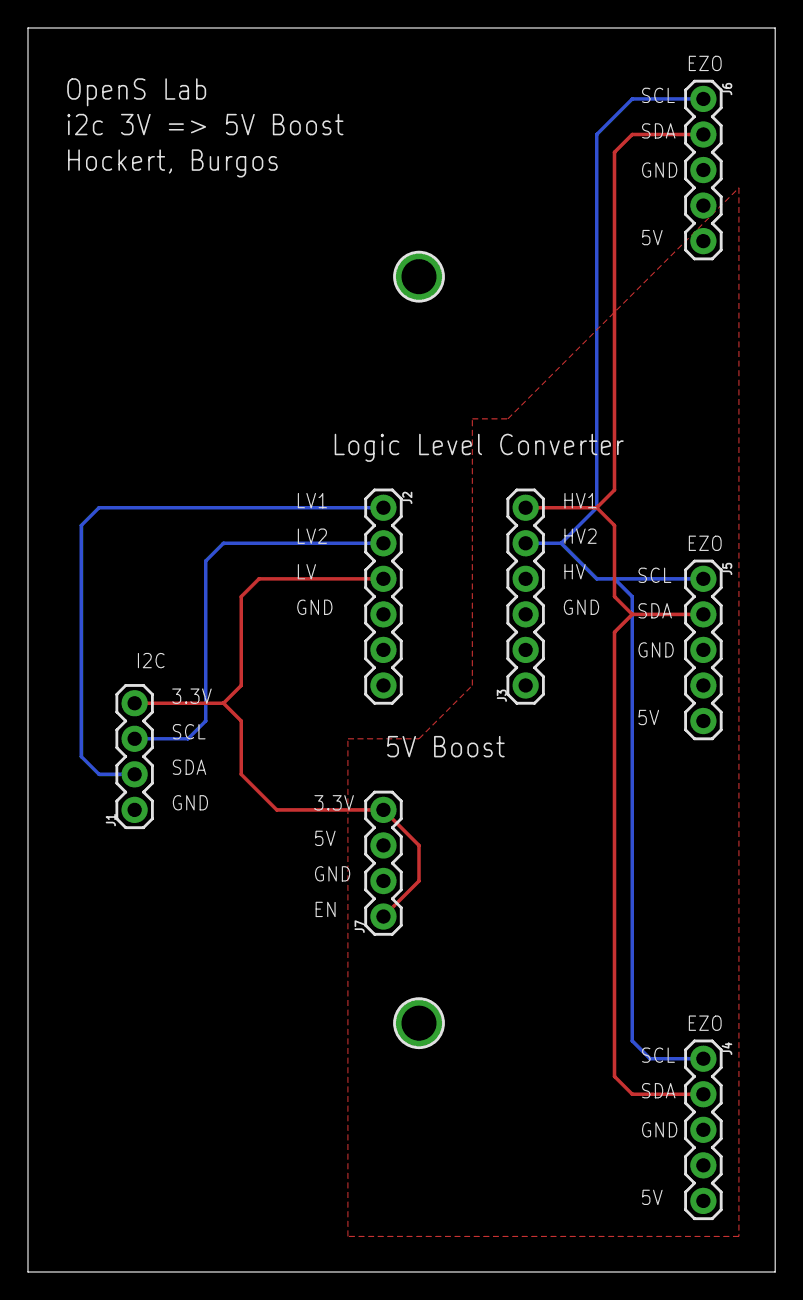
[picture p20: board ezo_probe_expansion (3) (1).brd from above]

Board: 2 copper layers, 53.4 x 88.9 mm, 9 parts (0 on the bottom side), 7 nets.

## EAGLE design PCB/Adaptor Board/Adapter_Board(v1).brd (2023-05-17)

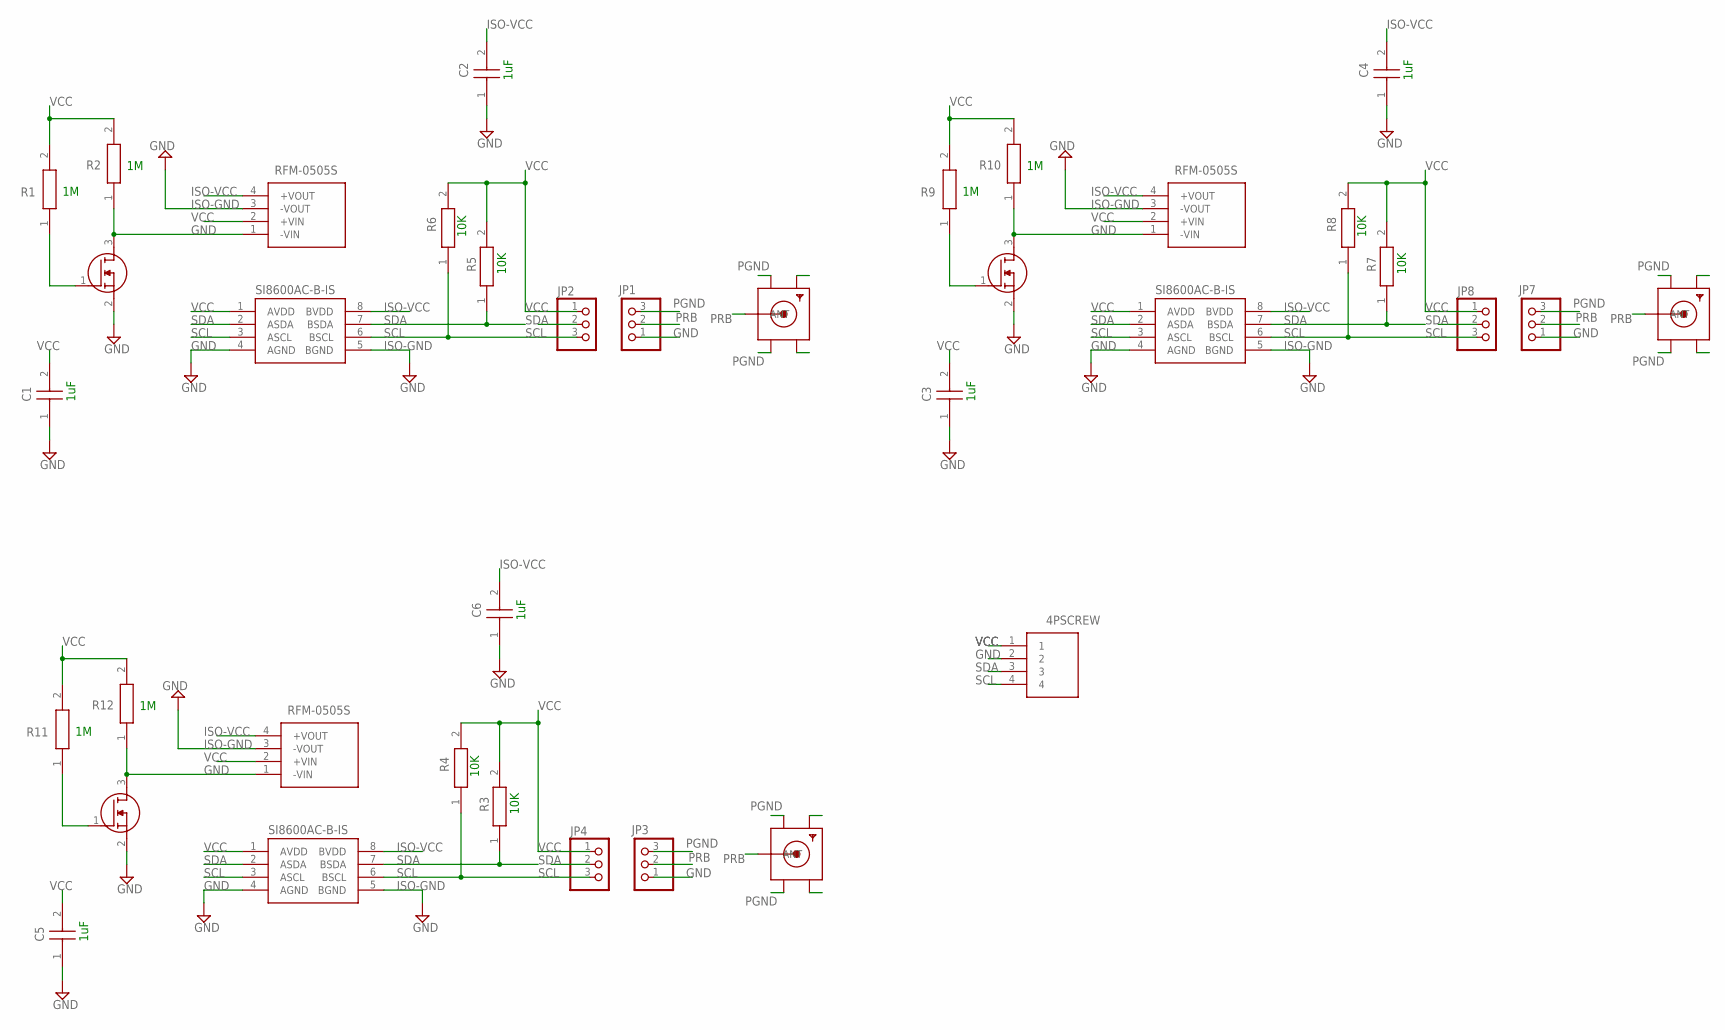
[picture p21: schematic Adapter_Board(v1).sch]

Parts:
4PSCREW: 1725672
C1, C2, C3, C4, C5, C6: C1608X5R1E105K080AC; CAPC1608X80N
IC1, IC2, IC4: SI8600AC-B-IS; SOIC127P600X175-8N
JP1, JP2, JP3, JP4, JP7, JP8: PINHD-1X3; 1X03
PS1, PS3, PS4: RFM-0505S; RFM0505S
Q1, Q2, Q3: BSS119NH6327XTSA1; SOT95P260X110-3N
R1, R2, R9, R10, R11, R12: ERJ-3EKF1004V; RESC1608X55N
R3, R4, R5, R6, R7, R8: CRCW060310K0FKEAHP; RESC1608X50N
X1, X2, X4: SMACONNECTOR_EDGE; SMA_EDGELAUNCH

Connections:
GND: 4PSCREW.2, C1.1, C2.1, C3.1, C4.1, C5.1, C6.1, IC1.4 (AGND), IC2.4 (AGND), IC4.4 (AGND), JP1.1, JP3.1, JP7.1, PS1.1 (-VIN), PS3.1 (-VIN), PS4.1 (-VIN), Q1.2 (S), Q1.3 (D), Q2.2 (S), Q2.3 (D), Q3.2 (S), Q3.3 (D), R2.1, R10.1, R12.1
ISO-GND: IC1.5 (BGND), IC2.5 (BGND), IC4.5 (BGND), PS1.3 (-VOUT), PS3.3 (-VOUT), PS4.3 (-VOUT)
ISO-VCC: C2.2, C4.2, C6.2, IC1.8 (BVDD), IC2.8 (BVDD), IC4.8 (BVDD), PS1.4 (+VOUT), PS3.4 (+VOUT), PS4.4 (+VOUT)
unnamed: Q1.1 (G), R1.1
unnamed: Q3.1 (G), R11.1
unnamed: Q2.1 (G), R9.1
PGND: JP1.3, JP3.3, JP7.3, X1.GND@2 (GND3), X1.GND@4 (GND1), X2.GND@2 (GND3), X2.GND@4 (GND1), X4.GND@2 (GND3), X4.GND@4 (GND1)
PRB: JP1.2, JP3.2, JP7.2, X1.P (ANT), X2.P (ANT), X4.P (ANT)
SCL: 4PSCREW.4, IC1.3 (ASCL), IC1.6 (BSCL), IC2.3 (ASCL), IC2.6 (BSCL), IC4.3 (ASCL), IC4.6 (BSCL), JP2.3, JP4.3, JP8.3, R4.1, R6.1, R8.1
SDA: 4PSCREW.3, IC1.2 (ASDA), IC1.7 (BSDA), IC2.2 (ASDA), IC2.7 (BSDA), IC4.2 (ASDA), IC4.7 (BSDA), JP2.2, JP4.2, JP8.2, R3.1, R5.1, R7.1
VCC: 4PSCREW.1, C1.2, C3.2, C5.2, IC1.1 (AVDD), IC2.1 (AVDD), IC4.1 (AVDD), JP2.1, JP4.1, JP8.1, PS1.2 (+VIN), PS3.2 (+VIN), PS4.2 (+VIN), R1.2, R2.2, R3.2, R4.2, R5.2, R6.2, R7.2, R8.2, R9.2, R10.2, R11.2, R12.2

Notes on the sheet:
10K
1uF

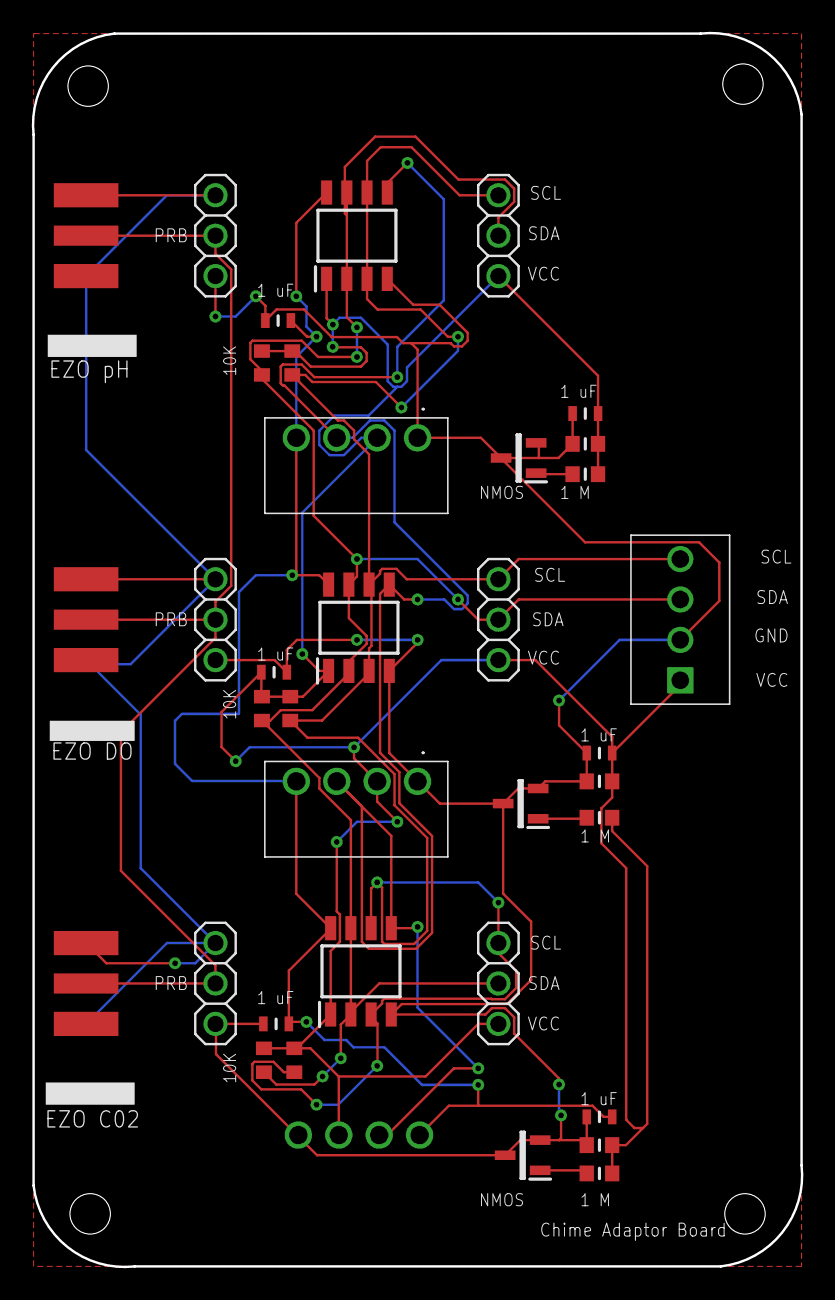
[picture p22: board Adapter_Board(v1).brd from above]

Board: 2 copper layers, 48.3 x 77.5 mm, 37 parts (1 on the bottom side), 11 nets.

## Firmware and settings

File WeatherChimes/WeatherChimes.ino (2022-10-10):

/**
 * In lab use case example for the WeatherChimes project
 * 
 * This project uses SDI12, TSL2591 and an SHT31 sensor to log environment data and logs it to both the SD card and also MQTT/MongoDB
 * 
 * MANAGER MUST BE INCLUDED FIRST IN ALL CODE
 */
#include <Loom_Manager.h>

#include <Hardware/Loom_Hypnos/Loom_Hypnos.h>

#include <Sensors/Loom_Analog/Loom_Analog.h>
#include <Sensors/I2C/Loom_SHT31/Loom_SHT31.h>
#include <Sensors/I2C/Loom_TSL2591/Loom_TSL2591.h>
#include <Sensors/I2C/Loom_MS5803/Loom_MS5803.h>
// If using Teros 10, Uncoment this line
#include <Sensors/Analog/Loom_Teros10/Loom_Teros10.h>

// If using SDI12, GS3 or Teros 11 or 12 uncoment this line
//#include <Sensors/SDI12/Loom_SDI12/Loom_SDI12.h>

#include <Internet/Logging/Loom_MQTT/Loom_MQTT.h>
#include <Internet/Connectivity/Loom_LTE/Loom_LTE.h>

Manager manager("4Gchime", 10);

// Create a new Hypnos object
Loom_Hypnos hypnos(manager, HYPNOS_VERSION::V3_3, TIME_ZONE::PST, true);

// Analog for reading battery voltage
Loom_Analog analog(manager);

// Create sensor classes
Loom_SHT31 sht(manager);
Loom_TSL2591 tsl(manager);
Loom_MS5803 ms_water(manager, 119); // 119(0x77) if CSB=LOW external, 118(0x76) if CSB=HIGH on WC PCB
Loom_MS5803 ms_air(manager, 118); // 118(0x76) if CSB=HIGH on WC PCB


Loom_LTE lte(manager, "hologram", "", "");
Loom_MQTT mqtt(manager, lte.getClient());

// If using Teros 10, Uncoment this line
Loom_Teros10 t10(manager, A0);

// If using SDI12, GS3 or Teros 11 or 12 uncoment this line
//Loom_SDI12 sdi(manager, A0);

// Called when the interrupt is triggered 
void isrTrigger(){
  hypnos.wakeup();
}

void setup() {

  // Wait 20 seconds for the serial console to open
  manager.beginSerial();

  // Enable the hypnos rails
  hypnos.enable();

  // Read the MQTT creds file to supply the device with MQTT credentials
  mqtt.loadConfigFromJSON(hypnos.readFile("mqtt_creds.json"));

  // Initialize all in-use modules
  manager.initialize();

  // Register the ISR and attach to the interrupt
  hypnos.registerInterrupt(isrTrigger);
}

void loop() {

  // Measure and package the data
  manager.measure();
  manager.package();
  
  // Print the current JSON packet
  manager.display_data();            

  // Log the data to the SD card              
  hypnos.logToSD();

  // Publish the collected data to MQTT
  mqtt.publish();
//  manager.pause(5000);

  // Set the RTC interrupt alarm to wake the device in 15 min
  hypnos.setInterruptDuration(TimeSpan(0, 0, 15, 0));

  // Reattach to the interrupt after we have set the alarm so we can have repeat triggers
  hypnos.reattachRTCInterrupt();
  
  // Put the device into a deep sleep, operation HALTS here until the interrupt is triggered
  hypnos.sleep();
  
}

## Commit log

2021-09-10 Arduino file with SDI12 dirty integration
    Used to test all hardware on WeatherChimes prototype, no Internet connectivity
2021-09-10 Connect to internet, only with Multiplexer
    Dirty Integration of device to HiveMQ. Uses a Multiplexer, and no SD card
2021-09-20 Flow Chart
2021-09-20 Update README.md
    Added more about WeatherChimes framework
2021-09-24 Removed secret info from arduino_secrets.h
2021-11-22 Mostly finalized version WeatherChimes
    [output.csv]
2022-01-19 Rolled back to working version of WeatherChimes. All 4 Chimes working
    [output.csv]
2022-01-31 WiFi low-power state, fixed config.h
    [WeatherChimes.ino]
2022-02-01 Create Base Plate
2022-04-28 Removed Opens MongoDB cluster from node-red flows
2022-06-08 Moved ArduinoMQTTClient to Dependencies
2022-07-23 Switched to loading all creds from SD
2023-03-07 Gerber files
2023-03-16 schematic pdf
2023-04-09 Add files via upload
    adaptor board
    [WC Adaptor.brd, WC Adaptor.sch]
2023-04-10 Air Wiring Issue resolved
    [Chime PCB v2.brd]
2023-05-16 Redesign of Chime v2.1. Made it smaller and added LEDs to solar charger circuit
    [Chime PCB v2_511.brd, Chime PCB v2_511.sch]
2023-05-16 EZO WeatherChime Adapter Board v1
    [Adapter_Board(v1).brd, Adapter_Board(v1).sch]
2023-05-16 Label Update
    [Adapter_Board(v1).brd]
2023-05-17 Added LEDs
    [Chime PCB v2_511.brd]
2023-05-17 Component label
    [Adapter_Board(v1).brd]
2023-05-17 GND Air Wires
    [Chime PCB v2_511.brd]
2023-05-17 All air wires good
    [Chime PCB v2_511.brd]
2023-05-18 Final touches
    [Chime PCB v2_511.brd]
2023-06-06 Final EZO Hydrology Adapter Board
    [Hydro_Board.brd, Hydro_Board.sch]
2023-06-06 Edited labels
    [Hydro_Board.brd]
2023-07-31 WeatherChimesv2.6 files from Google Drive
    [WeatherChimesV2.6.brd]
2023-08-07 EZO single board files
    [ezo_single.brd, ezo_single.sch]
2023-08-15 BRD file
    [ezo_single_smaller.brd]
2023-08-15 SCH File
    [ezo_single_smaller.sch]
2023-08-16 PCB Fixes for 3-probe expansion brd
    [ezo_probe_expansion (3) (1).brd, ezo_probe_expansion (3) (1).sch]
2023-08-16 removing old files
    [ezo_probe_expansion (1).sch]
2023-09-20 Adding final I2C_Extender and Chime PCB board file
    [Chime PCB v2.7.brd, Chime PCB v2.7_9.18.brd, Chime PCB v2.7_9.18.sch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]
2023-12-01 Tied the OFF Pin on the EZO Isolated Carrier board to high, hopefully fixing our issues of fried DO circuits
    [ezo_single_smaller.brd, ezo_single_smaller.sch]

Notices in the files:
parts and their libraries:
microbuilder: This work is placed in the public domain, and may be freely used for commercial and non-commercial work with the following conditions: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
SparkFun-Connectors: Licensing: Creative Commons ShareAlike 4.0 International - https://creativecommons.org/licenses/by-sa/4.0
